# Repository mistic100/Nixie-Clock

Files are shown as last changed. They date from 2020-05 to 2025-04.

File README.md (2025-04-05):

# Nixie Clock

([Check my new clock](https://github.com/mistic100/Nixie-Clock-IN12))

This is custom design of a Nixie clock using only integrated circuits (no micro-controller) inspired my various versions of the same design. It uses IN14 tubes.



[Pictures on my website](https://galerie.strangeplanet.fr/index.php?/category/73)

Rough timeline :
- 2011 initial researches of designs
- 2012 custom PCB designed on Eagle, most components bought
- 2019 PCB redesigned from scratch on Fritzing, manufactured and assembled
- 2020 design and 3D printing of the enclosure, final assembly
- 2025 new design using the control board from my [other clock](https://github.com/mistic100/Nixie-Clock-IN12)

What does this repository contains :
- Fritzing schematics + PCB layout
- SolidWorks models
- Various datasheets

_A note on the LED controller part :_
I used an IR controller which I had laying around. It is a common anode controller where the LED I bought are common cathode, this is why my design contains a section to convert the common anode control to a common cathode. This section is not described in the parts list.

### Controls

The digits are not always on to extend their lifespan, there is a capacitive touch hidden on the side of the enclosure which will power the tubes for ~15 seconds.

There are two push buttons on the back to set the time.

## Flaws

### Minutes and hours set

Unlike the other designs, I wired the hours and minutes set buttons between VCC and the CLK input of the third and fifth CD4017 in an attempt to manually control their clock. This does not work because the CLK is already in UP state half of the time (connected to the CARRY-OUT pin of the previous counter).
A simple solution is to wire the switchs between CLK of the first counter (after D17) to Q8 (128Hz) and Q4 (2048Hz) outputs of the CD4060, making the clock advance faster.

### LED controller output

There are three resistors on the controller output which need to be removed, and instead use a resistor for each LED.

## Sources

- [Mike's Electric Stuff - Build a Nixie-tube clock](http://www.electricstuff.co.uk/nixclock.html)
- [Peter J. Wendt - My Nixie Clock Project](http://www.mcamafia.de/nixie/ncp_en/ncp.htm)
- [Tr1tium - Yet another nixie clock project II](https://web.archive.org/web/20200124190202/http://tr1tium.com/projects/nixie2)

## Parts list

### Tubes
| part | qty. | notes |
|--|--|--|
| IN14 tubes | 6 |
| IN3 indicator | 2 |
| IN14 sockets | 6 |
| RGB LED | 6 |

### 1Hz generator
This section generates a 1Hz square signal.

| part | qty. | notes |
|--|--|--|
| 32768Hz crystal oscillator| 1 |
| 15pF capacitor | 2 |
| 10MOhm resistor | 1 |
| 33kOhm resistor | 1 |
| CD4060 binary counter | 1 |
| CD4013 dual D flip-flop | 1 |

### Dividers
This section successively divides the 1Hz signal by 10, 6, 10, 6 and 3.

| part | qty. | notes |
|--|--|--|
| CD4017 decade counters | 6 |
| 1N4148 diode | 12 |
| 100kOhm resistor | 9 |

### 24h & power-on resets
This section resets all dividers when hiting 24h and also ensure a proper power-on state.

| part | qty. | notes |
|--|--|--|
| BC547 transistor | 2 |
| 1N4148 diode | 1 |
| 10uF capacitor | 1 |
| 2.2MOhm resistor | 2 |
| 100kOhm resistor | 2 |

### Tubes interface
This section connects the counters output to each cathode.

| part | qty. | notes |
|--|--|--|
| MPSA42 transistor | 47 |
| 33kOhm resistor | 47 | transitor base |
| 33kOhm resistor | 6 | IN-14 current limit |
| 150kOhm resistor | 2 | IN-3 current limit |

### Tubes power
This section generates the high voltage power required for the tubes. It also integrates a system to only light the tubes for a few seconds after pressing a button.

| part | qty. | notes |
|--|--|--|
| HVPS1364 power supply | 1 | https://www.shop-tes.com/power-supply |
| 100nF capacitor | 1 |
| 100nF 250V capacitor | 1 |
| 39kOhm resistor | 1 |
| NE555 timer | 1 | used in mono-stable configuration |
| 10uF capacitor | 1 |
| 10nF capacitor | 1 |
| 1MOhm resistor | 1 |
| 100kOhm resistor | 2 |

### Misc
This is what I used for interfacing.

| part | qty. | notes |
|--|--|--|
| micro push button | 2 | used to set the minutes and hours by shortcutting the 1Hz to the input of the minutes and hours counter |
| capacitive switch | 1 | connected to the NE555 to light the tubes |
| DC power jack | 1 |
| lever switch | 1 |
| IC terminal block | 1 |
| 2.54mm male & female connectors | |

### Hardware
| part | qty. | notes |
|--|--|--|
| M3 threaded insert | 8 |
| M3 blind nut | 16 |
| M3 standoff | 16 |
| M3 thumb screw | 4 |
| M3 screws | 22 |

### Manufactured parts
- PCB by [AISLER](https://aisler.net)  
- Steel plate by [JohnSteel](https://www.john-steel.com)  

### 3D printed parts
All printed at home on a Creality Ender 3

- Enclosure, dark wood PLA
- Tubes and indicators holders, black PLA
- Transport cover, white PLA

## License

The Fritzing and SolidWorks files are distributed under the Creative Commons 3.0 BY-SA license.

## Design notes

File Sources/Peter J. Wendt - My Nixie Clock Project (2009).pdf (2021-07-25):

# My Nixie Clock Project

by Peter H. Wendt

Rel. 0.9.5_en, Last Update: Wednesday, 2009-11-18

Most common question: "Your what Clock Project ?"

Before Light-Emitting Diodes (LEDs) and Liquid Crystal Displays (LCDs) the electronic industry used cold-cathode tubes for displaying numbers, symbols and even characters. Even though they are called "tubes" they differ from "radio tubes" by having no heater wire to heat the cathode - and therefore run much colder. They do have a glass envelope but unlike to (most) tubes they are not empty: they are filled with a gas compound, mainly neon gas. If you apply a voltage between the anode (+ pole) and one of the cathodes (- poles) the character-shaped cathode is covered with a pink to orange discharge glow.
"NIXIE" was a trademark from Burroughs Corp. for their numeric display tubes. It is rumoured that they invented this kind of tube - or at least they got patents for it. There were many different types of these tubes: viewed from the side, viewed from the top, small ones, big ones, giant sized, types where a neon glows through a character-shaped mask and arrays of multiple nixies with multiplexed wires. Even early "multi-segment" types were available, capable to display letters like the later LED 7-segment arrays.

The animation below shows the button-like, top-viewed ZM1020. It is a Nixie with 15 mm (0.6") character height.

You got the idea, right ?
Now for some technical theory.

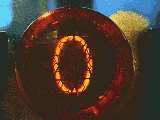
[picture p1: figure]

Basically these Nixie tubes are very simple devices. The following schematic will explain, how they work.

My Nixie Clock Project | http://www.mcamafia.de/nixie/ncp_en/ncp.htm
1 sur 16 | 25/07/2021 à 11:48

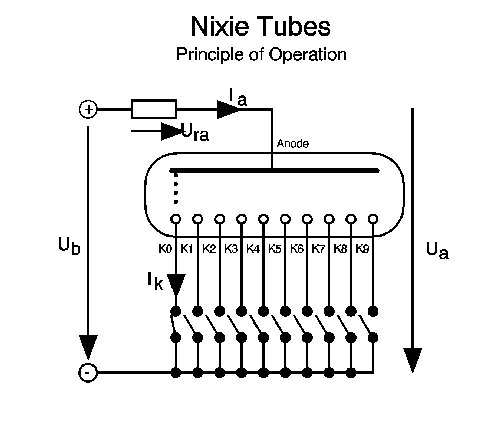
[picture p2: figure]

If you apply a voltage Ub the voltage drops across the current-limiting resistor when one of the cathodes K0 - K9 is tied to GND. The corresponding number-shaped cathode is then covered with a pink to orange glow. The values for the minimum Ub, the anode voltage Ua and the cathode current Ik needs to be taken from the nixie tube datasheet, but you can estimate 140 VDC for Ua and 2 mA for Ik as good starting values for most nixies.

If your Ub is about 220 VDC a 47K resistor / 0.5 Watts will do for some testings.
The datasheet for the very common ZM1080 / 1082 says that Ub should be at least 170 VDC and the Ik should settle at around 2 mA. Ua will then establish at about 140 VDC "maintaining" voltage (noted as Vm in the datasheet). The difference between Ub and Ua is the Ura that drops across the limiting resistor.

For a simplification we assume that the anode current Ia is equal to the cathode current Ik - you will have to tie only one cathode pin to GND at one time anyway. Nixies that use a "primer current" for faster ignition response have uneven anode and cathode currents. But we may leave that aside here.

Advantage: If you rig a multimeter in Milli-Amperes range into the (common) anode line during the testing you can track the current through the Nixie tube while connecting the cathode pins or leads to GND - without needing to meddle around with the meter wires. The unused cathode pins are left open (the term "floating" is used often). You will be able to measure voltages up to Ua on the pins not connected.
Further advantage: if you have several Nixies in a circuit, these have all one common Ub wire. If you install a mA-Meter in that line you get the total current drawn for all nixies. And can assume that the individual current is total current divided by the number of tubes you are using. This is not absolutely true - but we won't win the Noble Prize with a very precise research on that anyway.

Some quick maths to calculate the values for the limiting resistor

2 sur 16 | 25/07/2021 à 11:48

Ura = Ub - Ua -> 220 V - 140 V = 80 VDC

Ra = Ura / Ia -> 80 VDC / 0.002 A = 40.000 Ohms

Pra = Ura * Ia -> 80 VDC * 0.002 A = 0.16 Watts

Since there is no 40 KOhms resistor in the range of ordinary E24 5% standard resistors it will surely do if you pick a 43 KOhms type 0.25 Watts here, not to exceed the 2 mA cathode current.

# Calculation

## for the Nixie Anode-Resistor

Supply Voltage Ub | 220 | V
Anode Voltage Ua | 140 | V
Cathode Current Ik 2.0 | mA
Ura : | V
Ra : | K
Pra : | Watt
Calculate | Reset Cells

If you just press [Calculate] the values for the given Ub, estimated Ua and the given cathode current Ik are used and the output is the current across the anode resistor Ura, the resistor value in Kilo-Ohm and the thermal loss Pra of the resistor in Watt.
For your own calculation just overwrite the values in the upper 3 lines with what you need and then click on [Calculate] again.

220 VDC is quite a bit. How to get them safely ?

Well ... the professional approach is to have either a special transformer for the required voltages or at least an isolated 1:1 ratio separation transformer. If you live in the "low voltage" areas of the world where 110 VAC is the usual AC mains voltage you may survive a shock from the life wire. If you life in the "high voltage" areas like here in Germany the 230 VAC line voltage will surely kill you if you accidentially happen to be good grounded. A 1:1 transformer isolates the input voltage from the output voltage so you are not directly connected to AC mains. The 230 VAC that goes in comes out as 230 VAC - but you have no connection to Earth (GND) when touching any wire. You are -nontheless- toasted if you touch both wires at one time.
The professionals phrase is "galvanically separated" - it is good to know that.

Separation transformers are usually big, heavy and expensive. Not as expensive as your life of course, but enough to blow a budget. In our case however we don't need Kilowatt capabilities. A few Watts will do - so we can build our own separation transformer by simply using two small transformers "Back to Back".

The graphic below will show this simple solution.

3 sur 16 | 25/07/2021 à 11:48

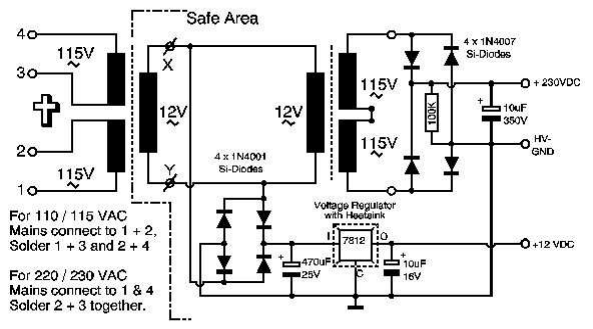
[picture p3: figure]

The transformers can be simple, relatively cheap print-type transformers with greater 4 Watts output power. The ones I used on my prototype clock are rated 4 VA (Volt-Amperes) with a single 230 V primary input and a single 12 V / 300 mA output. If you cannot get those - take two with e.g. 15 VAC or two with 8 V AC. The "intermediate voltage" between the two is of lesser importance, it is used for the logic board only. But at least the "one on the right side" must have a 230 V coil.
If you have two different transformers: the bigger (stronger) one must be the one connected to AC-mains. You cannot run a 10 Watt transformer from a 5 Watt type back to back for example. The 10 Watt has a lower resistance for the secondary coil - and the 5 Watt secondary coil is then overloaded. At least when you add load to it. It may work for some time however, but not reliably.

The 4 diodes 1N4001 for the low voltage circuit can be replaced by a block rectifier like the B40-C1000 for instance; the 4 diodes 1N4007 for the high voltage part can be substituted by e.g. a B1000-C125 rectifier bridge. This rectifier(s) must be capable to run continously with 350 V at least, so the minimum were a 1N4004 (rated 400V).

Other than that there are no secrets in that circuit. The 100 KOhms parallel to the 10 µF/ 350 V capacitor in the HV part helps - for safety - discharging the capacitor when no load is placed across the output. That's all. For your own pleasure you may add a 1 KOhms resistor at the +12V output and a red LED ... to remind you to the fact that the power supply is switched on.

With my two 4-Watt Transformers I get 15 V AC in idle between the transformers, 210 V AC idle voltage at the HV end. Also in idle the DC-voltages across the rectifiers are 18.5 V resp. 290 V DC. The high voltage however drops down to about 200 VDC when loaded with 4 x ZM1080 or 4 x ZM1020 Nixies and a total of 4.8 mA current drawn. A power supply built like that will suffice to play around with various types of Nixie tubes and get some insights on how they work.

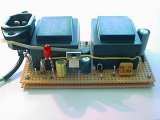
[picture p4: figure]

Important: Security - and some useful hints

4 sur 16 | 25/07/2021 à 11:48

If you use a power supply like that above you will need a medium-blow 0.315 Amps fuse in one of the AC main wires for protection when -in the worst case- the transformer goes south. You should also install the whole power supply unit in a plastic case so that it is factically impossible to touch any AC-line wire. That unit shown above is a prototype not intended to be really used that way.

If you can get one of these "wall wart" transformers that have about 500 mA at 12V AC you are fine off. In this case you only need one transformer in the clock itself and a power socket where the AC-Adapter plugs to. For the above schematic the left-hand transformer is your external wall adapter and the AC-input socket connects to the points marked with "X" and "Y" then.
Some DC-Adapters can be reworked: if you can open the case of it without destroying it - just unsolder the diodes and the filter capacitor that can be found in most of them and connect the output wires directly to the secondary side of the transformer. Then you only need the part of the power supply further above that is right from the left (input) transformer. The 12 V AC (or 8 or 9 or whatever) comes from the wall-wart and your second transformer must be choosen accordingly. And -if you go lower- the 7812 must be replaced by e.g. a 7508 (8 V output) or 7805 (5 V output). The circuit itself doesn't care much when running with anything between +5 and +15 V DC.

If you opt for that solution you can make your clock case from "more dangerous material", like steel, copper, sheetmetal, carbon-fibre or anything else conductive. You don't have the AC line fed into the unit and the worst thing that can happen is, that you shorten your electronics elsewhere and it simply doesn't work -or- damages the transformer(s).

Okay - but why building a clock from these Nixies ?

Good question. Today you can pick a lot cheapo LCD clocks from supermarkets for a few bucks. But - how do they look ? Simply boring.
Go back to the Nixie animation further above. Look at it for a while and I'm sure you can spot the difference.
I built digital counters and clocks with LED 7-segment displays and 74xx TTL-chips already in the 70's. The commercial clocks used ready-made circuits, offered alarm and such, but they looked cheesy cheap - didn't match my taste - and those who did were horribly expensive. So I made my own desktop clock.
Same reason for the Nixie Clock: a custom-made case, antique looking glass tubes somewhere in it or placed on top - a wide variety of possibly creative, unusual designs. You can make it from all material you'd always wanted to build a clock from. Wood, steel, acrylic plastic. Transparent, translucent or granite-solid.
However: the Nixie Clock described here is Just A Clock. Not a stop watch, timer, alarm clock or anything like that. You may add some "Bells and Whistles", but due to the nature of the circuitry it might be a bit complicated. More on that later.

Getting started with it: the proper timing

Heart of any clock is a source for a timing signal. Cheap AC-powered alarm clocks use the 50 or 60 Hz AC line to generate a more or less accurate clock-signal from it. Usually that would do -given that the accuracy over the whole year on the AC-line is within a 1 % range. Nontheless I'd decided not to use that. First reason was to be independent from the AC frequency. Secondly a crystal oscillator offers even better accuracy than line-AC and third I had a circuit at hand anyway

5 sur 16 | 25/07/2021 à 11:48

I used for a couple of applications in the past. Main advantage: it operates with a generic 32.768 KHz mini crystal widely available - and comes out with a 1 Hz timing pulse. The schematic below shows the circuit.

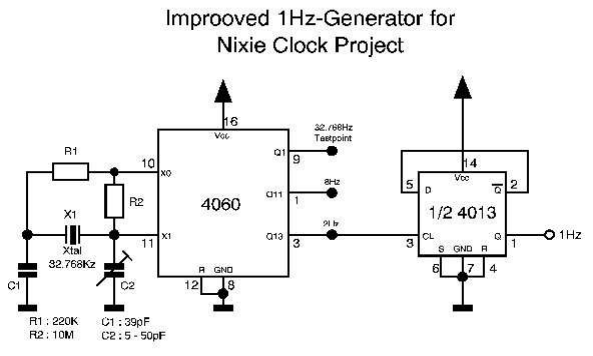
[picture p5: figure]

There are two resistors: R1 acting as current-limiting resistor and R2 bias resistor. This latter one is a) dependent to the circuit voltage applied to the 4060 divider chip and b) dependent to the current flow through the crystal and its capacity. I made good results with either omitting this one or using a 10 Mega-Ohms to start with. Your individual mileage may vary.

The crystal I used is a miniature clock crystal X1 in a round case
with 19 pF internal capacity. The "tie-up" capacitor C1 is a low-loss
ceramic type, the trimmer capacitor C2 is a standard plastic type. With a frequency counter connected to the 4060's pin 9 you can measure the buffered crystal frequency and adjust it to read exactly
32.768 Hz.

The 4013 RS Flipflop is used to divide the 2 Hz from the 4060 down

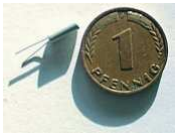
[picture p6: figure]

to the 1 Hz base clock. The second half of the 4013 might be used to divide the 8 Hz signal at pin 1 down to 4 Hz for a "fast forward" set mode - not shown here however. If you are not using the second half of the 4013: tie the pins 8, 10 and 11 to GND and connect 9 and 12. Pin 13 stays open. If you decide to use the 4013 pin 11 is your input, 13 the output.

It is highly recommended to keep the wires of the components (caps and resistors) short trimmed and the leads between the components as short as possible. If the oscillator fails to start up or dies after several seconds: make the bias resistor larger. It may go up to 10 MOhm with these miniature crystals - or even left away. The bigger HC-style crystals with higher internal capacity may require 100 KOhm - 1 MOhm bias resistors. If you don't want a trimmer capacitor you may use a ceramic capacitor of the same value as C1 as well. Doesn't hurt the overall accuracy that much.

In the meantime - after I edited this page for the last time - I had built numerous oscillators with the 4060 and got a lot responses from other folks. Alternative concepts for the trimmer position,

6 sur 16 | 25/07/2021 à 11:48

values of R1 and R2 and the C1 and C2 have been discussed.
Usually you have a datasheet for the mini xtal X1 to start with. This datasheet shows the internal capacity - which *use to be* about 16 - 19pF.
The value for the tie-up cap C1 should be 2x the xtal capacity. 39pF fits quite nicely here.
The value for C1 should be [xtal capacity < C2 < 3x xtal capacity], where 5 - 50pF covers the entire range.
Determining the values for R1 and R2 is more tricky.
While R2 could be ommitted in the best case for very dense packing of components R1 is essential for the clean function here. If it is too high the xtal fails to start - if it is too low the xtal enters "overtone mode" and the oscillator output frequency is either totally erratic or way higher than supposed.
For R1 220KOhm has prooved to be a good value, R2 should be 10M. If you have xtals larger than these micro-types your R1 needs to be reduced - down to 2K2 for a HC32 xtal and R2 might be reduced to 4M7 for stable operation.

The 4060 allowes to run at up to 4MHz @ 15V supply. If you have too much room and wouldn't care about two more 4017 dividers: pick a 3.2768 MHz xtal, leave R1 away or reduce it to 2K2, R2 to 10M, C1 to 22pF and install a 2 - 22pF trimmer. You get 200Hz at the Q13 - divided by 2 in the 4013 for 100Hz. Add two more 4017s and you are again at 1Hz with -probably- higher stability due to the higher reference frequency. However: you should not test the 4060 frequency at pin 9. The probe capacity will alter the result. You should test at O4 (pin 7) and your counter should read 204.800 Hz. The trimmer allows a change of about +/- 25 Hz. If you don't have one adjust C2 to the center, where about the half of the static "leafes" are visible. That will do to for most cases.

Step by Step: the dividers (Seconds, Minutes and Hours)

At that point we've got to hold for a moment and think about a basic design question:
"Do we want a seconds display or only minutes and hours ?"

In either case we need two 60-stage dividers. Building a clock without a seconds display saves room and driver transistors. Let's have a look at this part of the circuit.

7 sur 16 | 25/07/2021 à 11:48

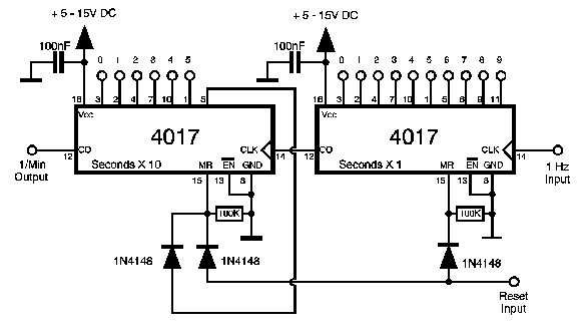
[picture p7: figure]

The CMOS chip 4017 is a "5-stage Josephson decade counter" with built-in code converter. Each low-to-high transitition (= "positive edge") on the clock input 14 advances the counter one position up from Q0 to Q9, which go to high level then. A logical "1" signal on the reset input 15 sets it back to Q0.
To count the seconds properly we have to pull the first counter reset to GND with a 100K resistor, which causes the counter to count from 0 to 9 with every clock signal. At 9 it jumps back to 0 with the next clock pulse and the "Carry Out" signal at pin 12 changes from "0" to "1", which counts the second counter one position up. The second counter has the Q6 output wired to the reset pin. After the 59th clock pulse it jumps back to "00". Any of the "Carry Out" signals changes back from "1" to "0" after receiving the positive edge of the 6th clock pulse.

The capacitors on each pin 16 are local buffer caps only. They are there to reduce the effect of local voltage sags. This is mainly an issue when the circuit is built on experimental board or with no board at all. Given you have a stable, clean supply voltage it will surely suffice to leave them away or add one or two of them on the chips farthest away from the point where the supply voltage is fed into the circuit.

The "100nF" rating seems to be a tad uncommon to some people. It has been brought to my attention that it may lead to some confusion and I had been asked if I meant "microfarad" instead (but didn't have the proper sign). No - it is Nanofarad. Or - alternatively - I could use "0.1 µF" here to clarify what I meant.

The Seconds Divider is followed by the Minutes divider. Looks in most of it like the Seconds Divider - but the In and Out is named different. Functionally they are alike.

8 sur 16 | 25/07/2021 à 11:48

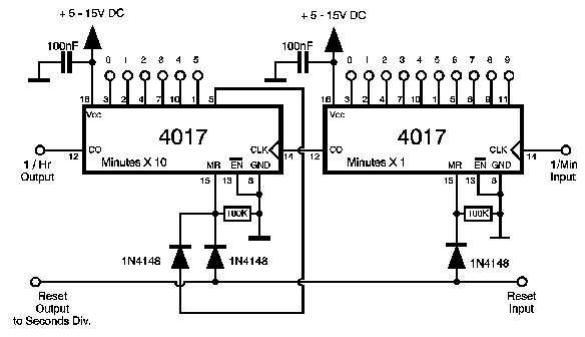
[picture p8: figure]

Now comes a tricky part. In Europe (where I live) we have a 24-hours display. We're not "AM/PM" guys over here. 24 is a bit hard to decode, since it is neither a roll-over nor is it just a single digit rollover. So note the reset-logic here. It is a wired-AND with 2 NPN-transistors that pull the Master Reset up when a "4" appears in the LSB while there is a "2" on the MSB hours display. Neat, eh ?

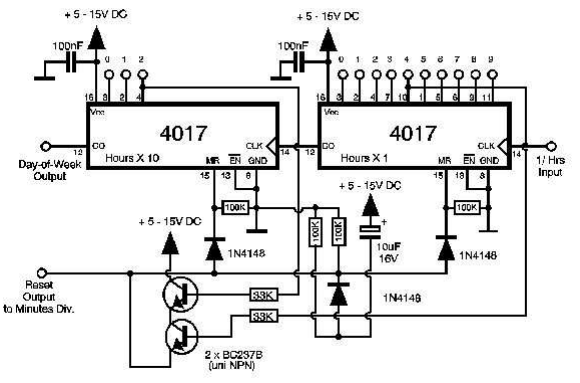
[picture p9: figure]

Also note the 10 µF capacitor, the 1N4148 diode and the 100K resistor. These three form the

9 sur 16 | 25/07/2021 à 11:48

"Power-On Reset" circuit that pulls the Master Reset line up for some time after a power on occured to bring the counters to all-Zero displays. It might be unneccessary - but you never know with these CMOS counters.
The carry-out signal from the last counter might be used to create a "Day of Week" display with another 4017 and e.g. a backlighted frontpanel. Be creative.

If you decide to have "US-style" AM-PM display you will have to slightly modify the hours divider.

The counting on the hours display does not start at 00:00 but at 01:00. All numerals need an offset. The Q0 output sets the "1", the Q1 output the "2" and so forth. Due to that you have to move the input of the 10-hours from the "Carry Out" (pin 12) to the pin 11, which advances the 10-hours with every transition from "9" to "0".
While the counting resets at one minute after "12:59" at "13" in the hours display (and not at "24" after "23:59") you need to alter signal for the Wired-AND to the reset the hours stage to pin 2 on the 10-hours and pin 4 on the 1-hours.

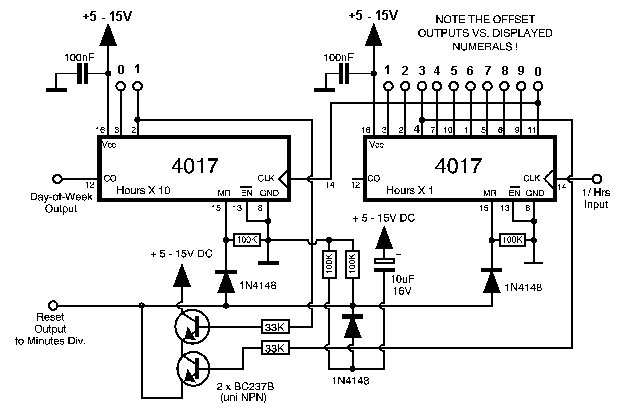
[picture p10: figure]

More power: Driving the Nixies

Problem with the Nixies is the relatively high voltage they operate with. Each cathode pin that is not grounded is pulled up due to the electron migration inside the gas-filled tube to near the anode voltage Ua. This may be 140 VDC - or above on some types. A circuit that pulls down a cathode from this "idle voltage" to GND must be capable to handle it. If you use a NPN transistor the Emitter (E) is tied to GND and the Collector (C) is connected with one of the cathode pins. The Base (B) is connected to the counter outputs via an appropriate current-limiting resistor. The "Collector / Base Voltage with open Base" Ucb0 specs for the transistor must be higher than the idle voltage on the cathodes. That's the voltage a transistor can handle when being not conductive

10 sur 16 | 25/07/2021 à 11:48

(= not switched on). This disqualifies most common transistors, since their Ucb0 is only 15 - 60 Volts.

But - there are matching transistors available. Namely those designed for TV-purposes (video stage, color final stage, deflection circuits) or various HF and switching transistors can be used. If you have access to a listing of transistors with their base data you will easily find some matching types. Most common and low-cost transistor is the MPS-A42, which is a NPN transistor with Ucb0 = 300 V, Ic = 0.5 Amp and Ptot = 0.625 Watts designed for TV video stages. In Germany we pay 0.08 Euro (about 7 cents) for one - comes cheaper if you buy 100 for example.
Also useable are BF118, BF179C, BF259, BF338, BSS48, BUW37 (all with a metal-can case) or BF413, BF420A, BF422A, BF483 (plastic case), AT1, AT2, DC or NMPSA-42 (SMD types) to name a few.

Alternatively you could tie down all cathodes to GND with a resistor of 100 KOhms to reduce the idle voltage - without starting the cathodes to glow already. In this case a more versatile transistor with a Ucb0 of least 65V like the BC174B or BC546 or BC846 should do. However - you need 3 times more resistors.

The schematic below explains the different driver circuits.

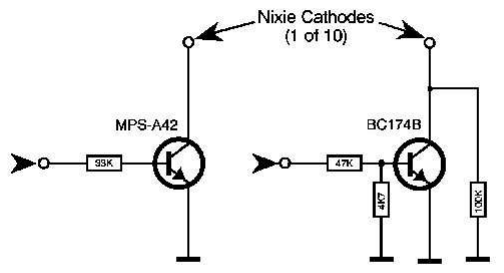
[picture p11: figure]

The left circuit is the pure simplicity: only one 33 K resistor between the counter output and the base of the transistor. While in the circuit on the right you have an additional voltage divider with a 47 K / 4.7 K resistor between the counter output and the base plus an additional 100 K "pull down" resistor that reduces the voltage between the turned-off cathode and GND.
To tell the truth: I didn't bother much with the circuit on the right side. In fact I got the idea from an old TV program display circuit that uses Nixie tubes. But the MPS-A42 transistors are fairly cheap and there's no need to switch to some low(er) voltage types, which aren't much cheaper - if at all. But maybe you happen to have several hundreds of them around ... feel free to use them.

The circuit itself is simple: the positive signal from the counter output passes the current-limiting

11 sur 16 | 25/07/2021 à 11:48

33 K resistor and turns on the Collector-Emitter path, which then grounds the cathode pin of the nixie. This turns on the neon glow for that cathode.

Under Control: Switches for setting the clock

Since this clock is only a counter it does not get the time "by automatic". However: since it has "Auto-Zero" function you could try plug it in at midnight exactly ...
So we need switches. I like clocks where minutes and hours can be set independently. And which has not to cycle through the entire 24-hours-counting in fast forward and then set the "finetuning" with a slow mode switch. I prefer setting the minutes, then the hours. Once I goof on that I don't need to re-run once again. And again. Maybe.

The solution is pretty simple. Two toggle switches, one between the seconds and minutes divider and one between the minutes and hours divider will do the trick. Look here:

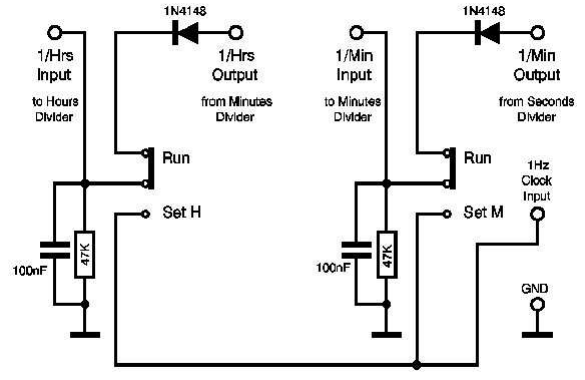
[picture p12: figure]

The common contact on either switch is connected to the input of the counter to set (minutes or hours). The resistor / capacitor combination debounces the switch a bit to avoid "scrolling" when switching back from set to run mode.
The upper (NC - now closed) contact is connected with the output of the previous counter. The Diode is for decoupling. It is not always neccessary, but might help avoiding problems, when the switch has "take-over" contacts that close both contacts momentarily while toggling.
The lower (NO - Now open) contact is connected with the 1 Hz base clock from the 1Hz-Generator. If the clock is too slow for your feel (especially on the minutes count-up) feel free to use the 2 Hz from the Pin 3 (Q13) of the 4060 directly or even use the 4 Hz signal that can be generated from pin 1 (Q11) of the 4060 and the second half of the 4013 Flip-Flop. Or use pin 2 (Q12) on the 4060, which offers 4 Hz already.
12 sur 16 | 25/07/2021 à 11:48

Ticking the seconds: A blinking colon

Those who opted to build a 4-digit clock with Hours and Minutes only (and save 16 transistors and 16 resistors at least) may wish to have something that indicates the seconds pacing on. Analogous to the odd blinking ":" on other digital watches.
Easy done. If your Nixie has a decimal point you could use one of those. Nixies that have a decimal point to the right of the number should use the one in the 1 / Hours digit (LSB), with a left-side decimal point you use the one in the 10 / Minutes digit (MSB). No special treatment required. The anode current on the Nixie goes up a bit - but that shouldn't harm anything.

Those who use Nixies without decimal points or aren't attracted much by the look may use a single neon-lamp in the middle between the hours and minutes display. See the schematic below.

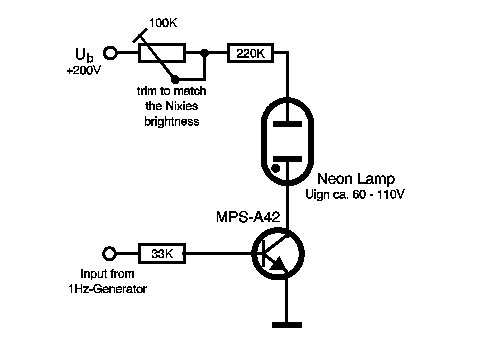
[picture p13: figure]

This is how the single, middle flashing neon lamp looks on my second prototype: it is a relatively long and slim lamp I recovered from some electronic crap in the early 70s ... almost 3 decades later it came handy to act as a blinking colon in a home-made Nixie Clock. Life is funny.

You could also use a LED - or some "Magic Eye" tube that alters height / angle during the seconds ticking. But "real tubes" require a

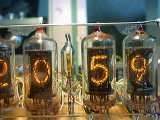
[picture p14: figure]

heater supply which is several 100 mA normally - while the entire circuit with the 8 CMOS chips, the driver transistors and such takes less than 10 mA. The Nixies take another 5 mA from the 220 V supply - and that's all. If you stuff in a "radio tube" you will have to extend both: your low-volt and high-volt supply as well. So far you come away with about 6 Watts electric energy - given that the two transformers have an efficiency of about 80 %.

Bells and Whistles: Adding extra-functions

13 sur 16 | 25/07/2021 à 11:48

(Not yet fully approved)

An easy method to add an extra function is using an integrated sound circuit. Usually these chips are positive-edge triggered. Means: you pull the input high and the sound plays. Given you got a chip with a "Big Ben" bell tone you simply add an AND-gate output (or two transistors as for the "Hours" reset circuit) to the sound-chip "activate" input. The AND-gate input is connected with the "0" outputs (pin 3) on the minutes divider 4017s.

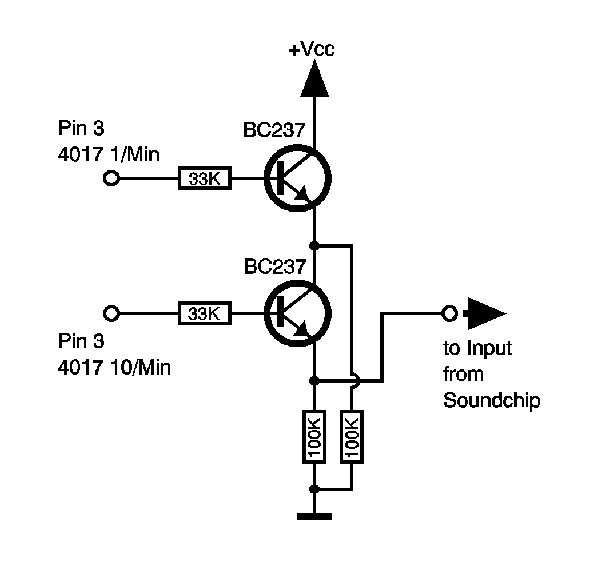
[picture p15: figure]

Result: any full hour when the display jumps to "00" in the minutes the sound is triggered. Hint: include a switch to shut off the sound. Sometimes these "good" ideas turn out to be somewhat ennerving on the long run. (Big Grin !).

Finally: some pictures from my prototypes

So far I made three different prototypes. After some testings and trials the circuit has stabilized to the components shown above. There is however a lot room for improovements or changes, add-ons and whatnot. Especially the switches for setting the time are subject to permanent change. A printed circuitboard is also (yet) missing, but I'm working on it.

Here are some pictures of the two working clocks.

14 sur 16 | 25/07/2021 à 11:48

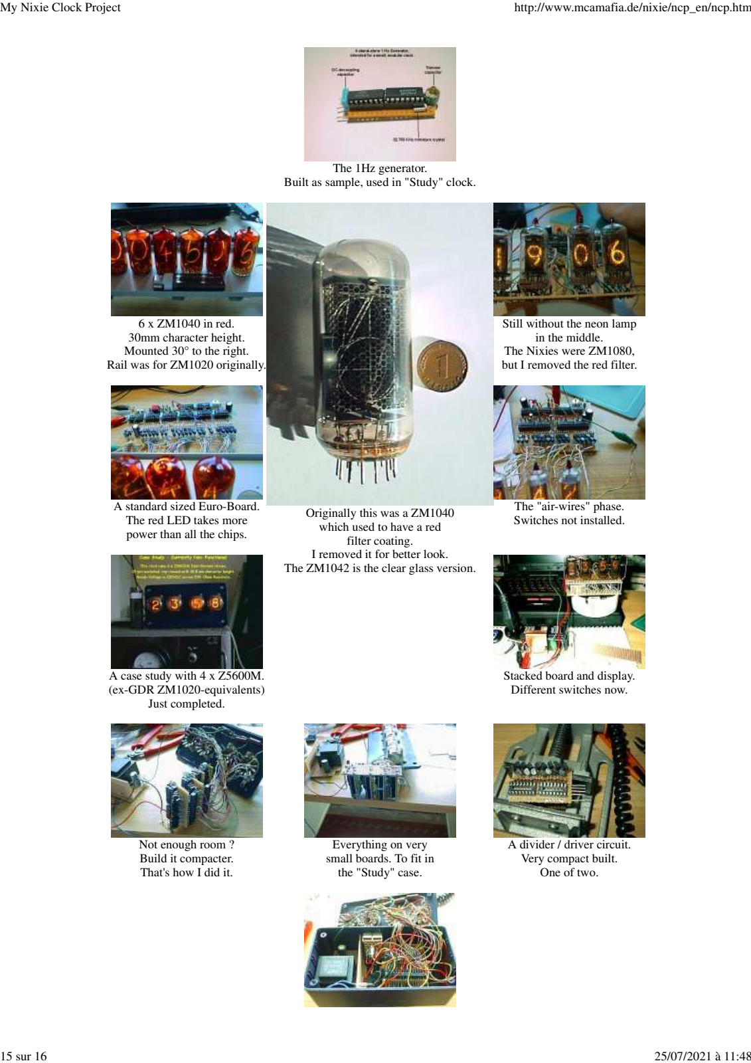
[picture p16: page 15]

The 1Hz generator.
Built as sample, used in "Study" clock.

6 x ZM1040 in red.
30mm character height.
Mounted 30° to the right.
Rail was for ZM1020 originally.

Originally this was a ZM1040 which used to have a red
filter coating.
I removed it for better look.
The ZM1042 is the clear glass version.

Still without the neon lamp in the middle.
The Nixies were ZM1080,
but I removed the red filter.

A standard sized Euro-Board. The red LED takes more
power than all the chips.

The "air-wires" phase.
Switches not installed.

A case study with 4 x Z5600M. (ex-GDR ZM1020-equivalents) Just completed.

Stacked board and display. Different switches now.

Not enough room ?
Build it compacter.
That's how I did it.

Everything on very
small boards. To fit in
the "Study" case.

A divider / driver circuit. Very compact built.
One of two.
15 sur 16 | 25/07/2021 à 11:48

A look inside.
Yes - it is pretty tight filled..

Other related Topics:

My Nixie Tube Mini-Tester - My Little Nixie Collection A "7-Segment-To-Nixie" Decoder (very strange thing) Dimming the Nixies - A Nixie Clock For Everyone ... !

© 2001 by Peter H. Wendt

Maintainer Notes: all tips given in this document are without any warranty.
If you accidently kill yourself, burn the house or blow everything - your problem. Switch your brain on, think, reconsider and then act. But first: Think !
You may however pick anything you like from this page if you quote the original source.

Feel free to leave me a note, reports, pictures or ask questions if you like.
I try to respond if my time allowes, which is not always the case. Sorry. I have a lot hobbies and a job.
16 sur 16 | 25/07/2021 à 11:48

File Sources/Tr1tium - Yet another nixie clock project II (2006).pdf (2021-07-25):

The Wayback Machine - https://web.archive.org/web/20200124190202/http://tr1tium.com:80/projects/n…

## yet another nixie clock project II

almost three years of no work on the first nixie clock and the bug has bitten. it's time to start again! and, who'd've thought, but after the start in oregon, the move to new york and taking the clock to work to show colleagues and interns, then back home again, the darn thing still works and fast forwards...wow! ok...on with the show.

as you may have noticed, the first clock was really one of the first projects i had ever done and i learned *a lot*. on top of that, my skills greatly improved over time. heck, check out the new timing circuit in the clock to see the difference. i've still got a lot to learn, but only time will tell. anyway, the hope here is to keep everything a lot smaller and a bit more modularized. plugs here and there and have a few pieces that can be disconnected from each other and reconnected so that they will be easier tested and one day fit inside a nice looking project box/display/something like that. that's the hope anyway...

once again, i'm using peter wendt's nixie clock page for reference and only posting changes and things i'm doing so you should check it out to see what's going on.

as a note about updates, additions and the dates: sometimes i put the date in to help keep track of where i'm at and what's going on update wise. i guess it's a little blog-esque. most of the time i update and fix errors and don't mention it unless it's bad and nasty.

11/12/2005: so, the first thing on the list was parts. last time i went around, ordered parts, visited stores, drove here and there, ordered parts, drove here and there...it went on and on. this time i tried to piece together everything i'd need and order it all at once and just ordered it from mouser. they've got it all... but, for some darn reason i still went to radio shack and bought a few things. weird i know.

the parts arrived and the first attempt was the power supply. it's really the original design, but i did use a 115V -> 12V AC adapter so it would hang on the wall and not be stuck inside the clock. it takes up less space and is suppose to offer some safety advatages. on top of that, i stuck an LED on the 12V output (after the voltage regulator) so that when it's plugged in i'll know if it's on or not. here's the design and a few pics.

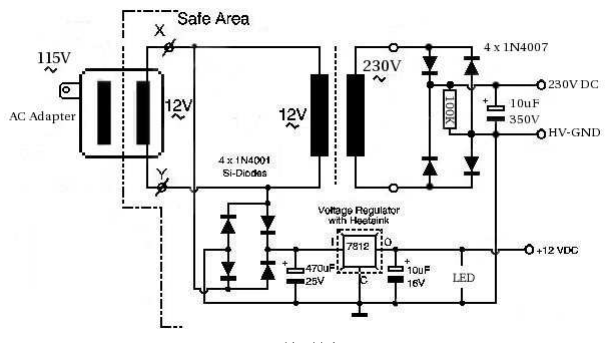
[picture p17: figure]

and the original

yet another nixie clock project II | https://web.archive.org/web/20200124190202/http://tr1tium.com/projec...
1 sur 13 | 25/07/2021 à 12:00

the 4 pin on the left is the 12V AC in from the adapter and the "green" plug is actually a male/female adapter together for the 230V out. the white 2 pin in the middle, by the heat sink (you can barely see) is the 12V regulated out. click on them to see bigger, commented pics.

and the darn thing even tested out ok! the regulated voltage hits 11.96 which is pretty darn close to 12V and the step-up transformer is reading 251V because it's not under load. you'll notice that this time around i'm using a straight 12V -> 230V transformer instead of the 12V -> 115V and voltage doubler like i did before since i got a lot of my parts from radio shack before i discovered mouser (or any real dealer), and of course they didn't have any transformers like that. this time around, since i got all my parts from mouser, the transformer existed. either way, it works and you do learn a lot as to why it works. as i thought about which i'd rather do i figured this would be good to try out since i didn't do it last time. course, if i understand right, the output from the transformer is much cleaner than from a voltage doubler.

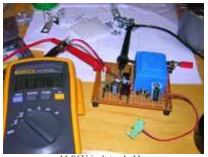
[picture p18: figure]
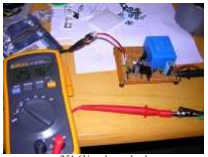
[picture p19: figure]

11.96V isn't to shabby | 251.6V under no load

i ordered the tubes from sphere research again, and, once again, no problem. a call, a payment and like 3 days later the tubes arrived. this time i got the siemens zm1332 tube. a little bit smaller than the tubes from last time, but they were brand new this time and sure look nice. <g>

and it even lights a tube!

a grounding side note, since this got me last time... you'll notice that if you compare the voltage doubler power supply of the first clock and the diagram of this power supply (see above), there's a connection between the high-voltage ground and the low-voltage ground present. turns out, and i didn't know this originally, that ground doesn't equal ground. eg. low-voltage ground is different from high voltage ground. so, when i built the first clock the nixie tubes wouldn't light up even though everything was counting correctly. this was becaue the high-voltage ran through the transistor, but there was no low-voltage ground, so nothing happened. i gave my dad a call, talked with him a bit and he told me to connect the low-voltage ground to the high-voltage ground to solve the problem. i did, and wham, the problem was solved. the clock started working. so, was this a big "it worked one time"? nope. in the blinking tube movies below the 12V runs into the transistor and the only ground directly connected is the high-voltage. since this power supply connects low-voltage ground and high-voltage ground, it worked, just like it was suppose to. so, hopefully this makes sense to anyone but me and isn't complete bull. :)

11/19/2005: after the power supply it's time to make the timing circuit. i actually started last weekend, but it didn't go so well. everything else went amazing, considering it was the first time at such a project in 3 years, but when i got to the timing, nothing. so, back to work. but! this time around, instead of doing everything with a soldering iron i used a pluggable breadboard. and that made it good. in about an hour it was working and it looks like the reason last week didn't work is because the 4060 chip is blown and some of the capicitors from the radio shack mixed box are bad. how'd i know last weeks chip was blown? i found that the 4060 intakes 11.96V and outputs ~6V...not to good. on top of that, it's hot as heck like it's just burning off voltage. something isn't right with it. luckily i have a second one, so i used it and, sure enough, with the plans i had originally, it works! and it stays cool.

2 sur 13 | 25/07/2021 à 12:00

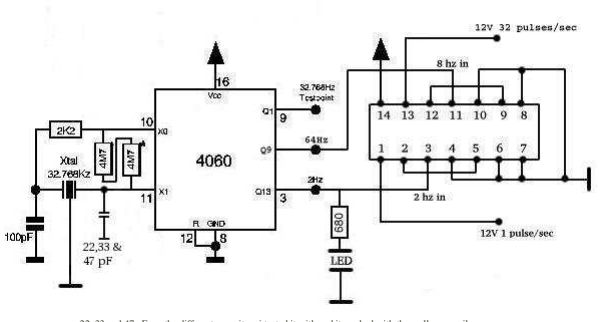
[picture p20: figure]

22, 33 and 47 pF are the different capacitors i tested it with and it worked with them all. your mileage may vary. note: timing has been redone a bit, so see below see the original

afterward i soldered everything together and put the 4060 in and...nothing! what! i moved it back to the test and still nothing. then i found that it's outputing under 11V, around 10.5V to be exact. i have a bad feeling about this one too so i've ordered some new 4060s from a different manufacturer and we'll see if i just screwed them up, or if they're really that bad.

11/20/2005: i decided to pull the 4060 from the old clock and test it out. and, what do you know, it worked in the test setup without a hitch. the circuit i built needed a bigger capacitor, so i changed it from 22pF to 39pF and it worked. the led blinked without a problem. so, either the chips i got were bad, or i wouldn't trust them. the one that worked (and i've reordered) is the NTE-4060B.

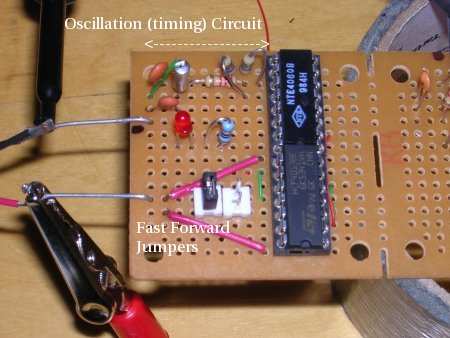
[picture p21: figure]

this circuit has the jumpers because i wanted to choose between two different fast forward speeds without having to resolder. the circuit is the same as above, it just has the jumpers inbetween the 4060 Q9 outpin and the flip-flop input pin 11 (i'll update it soon). the two speeds are 4 and 16. i was going to use 8 and 16, but the 4060 doesn't have 16Hz out. i'm sure there's a reason, but it seems weird...

3 sur 13 | 25/07/2021 à 12:00

12/4/2005: i got the new nte4060 chips, put the old one back, inserted the new one and everything worked just like it was suppose to. yay! so, in playing around i bought a cheap plastic container so it could be the first box (it's just a test really). i drilled some holes, mounted stuff and we'll see how everything fits as we go along. the biggest thing is that i tested the nixie tube with the timer to see if it would turn on and off every second and how the tubes would look. as a side note, next time i put chips next together i'll put at least one space in between. the 4060 has flat edges, but the flip-flop doesn't. it buldges a bit and getting the two to fit next to each other like this might have been pure luck. but, it's working for now. <g>

12/11/2005: oscillator changes at hand! originally i built the timing circuit, got it going and was happy. but, it takes around 6 seconds to get going. so i decided i'd play with it and see what i could do. i tried adding a bit more capacitance to the 22/33/47pf side of the crystal (see above) and by darn, that sped it up a hair. then, out of screwing around, i added a bit to the 100pf side. boy, did that have a big effect! the start-up time dropped from six seconds to around 3 (btw- this was all on the plug board). so i calculated the capacitor ratio between the two sides and found out it was about 5.2. i don't know why i did this. it just seemed like a good idea. since i have a 39pf soldered in i had to test it with a second 100pf capacitor, doubling the pf on that side. wow! it dropped from a 6 second startup time to ~1 second. so, i sold myself on it and soldered it in. that was saturday. then, on sunday, i figured it was a bit strange. why did it work? so i dug around a bit and tried to refamiliarize myself with timing, crystals and osciallation. if you're interested, i found some good links at ECS Inc. (i have the tfc-3x8 crystal), wikipedia and crystal oscillation, a pdf description of circuit design, and an in depth discussion at google groups. anyway, i decided to look at the docs for my crystal and found the circuit design recommended varied a bit from the original. so, i tested it out (see below) and on the first round using a 22pf cap the crystal started osciallating in about 1 second! i switched to a 39pf (note that both are 22 or 39 unlike 100 and 4-40) and it started the same, in about 1 second. then, i attempted to do the calculations to find out what capacitor size would give me the "load capacitance" for the crystal as defined by the manufacturer and came up with 15pf (see the pdf description, page 3 i mentioned above). so, i switched to that and the darn thing starts up in less than a second! it's kinda crazy. here's the different layouts and even movies to go along! and the original 6 second start can also be seen.

with 2 100pf caps

-->

using either 22pf or 39pf caps. note the 2K2 to 330K resistor change.

-->

using the 15pf for
calculated "load capacitance"

granted, this is all on the plug board and we'll see if i can solder everything together correctly...but it looks good. in comparison, it takes the version one clock a bit over two seconds to start up, so this is much, much faster. but, keep in mind, you should probably check out the docs for the crystal you have and see what they recommend for a circuit design. that's what seems to have solved the "how long it takes to startup" details. i guess we'll see for sure...

12/18/2005: today i soldered the timing circuit together i had tested out in the plug board and it was a success. the little led starts to blink in what must be around a half second and when i plugged it into the test nixie tube you can't tell. you push the power button and it just starts flashing each second. watch it if you want...

the layout is pretty similar to the original, but here it is, and it looks as though checking to see what the crystal manufacturer recommends will be a lot of help. the design might be just like the original, it might be like this and it might be different. i know, that isn't really helpful is it. :) (here's the doc for the ecs-3x8 crystals i've used)

4 sur 13 | 25/07/2021 à 12:00

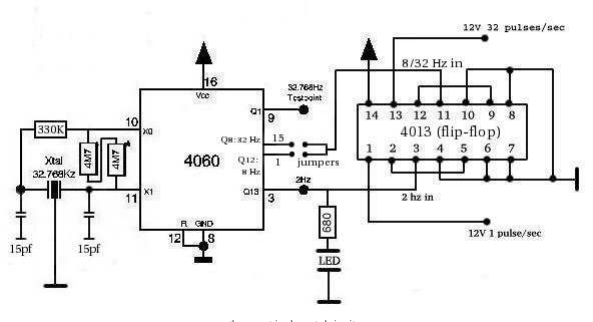
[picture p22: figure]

the current implemented circuit

and, as i've mentioned, i wanted to start putting things in some container so i could see if they were small enough and get some idea of how the parts were fitting together. plus, it would give a good place to mount switches and the a/c adapter plugin. so i got a cheapy tupperware container and started mounting things inside. who knows if this will actually work, but we'll see...

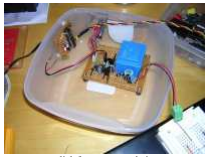
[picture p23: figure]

click for commented pic

12/26/2005: now that we've got the timer going and the power supply ready it's time to move to the world of counters and nixie tubes. so, first off, i worked with the seconds decade counters. for weeks now i've been attempting to visualize, draw out and think about how i'll lay this stuff out in an attempt to minimize wire criss-cross and help the problem of all the little things that will infest the board. so, in a first attempt i put the decade counters on a small board about 2x3 inches.

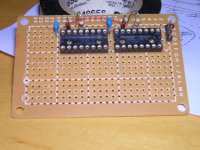
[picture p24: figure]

see the original seconds and minutes decade layout

but, after i built it, and before i added all the good stuff to make the nixie tubes cycle, i decided that in order to link three of these together there would be to many wires and connections and it would be better to go back to the single board layout like i did before. so, the next day i worked on this i laid out a few more sockets and rebuilt the seconds decade counter area.

5 sur 13 | 25/07/2021 à 12:00

see the original seconds and minutes decade layout

i did some tests and was able to see that it is counting corectly, just like the first time! if i held the volt meter on one of the pins of chip 1 (say 4) and waited for the DMM to blink 12V, then i would count "one-one thousand, two-one thousand..." and around the same time i hit 10 seconds, it would blink 12V again! then, if i go to the second decade counter i can see that pins are live for 10 seconds like they're suppose to be and i can follow from pin to pin and see that things reset and go from 0 -> 1 ... 4 -> 5 -> 0 just like it's suppose to. i even hooked up the test nixie tube i have in the plug board to the first counter so that evey ten seconds it would blink on for one second. then, i hooked it up to the second decade counter so that it would stay on for ten seconds out of every minute. i also tested the reset to see if that would work and surprisingly, it did. i think things went well today. :) since things are counting right it looks like it's time to add a few tubes and actually get things ticking...

12/30/2005: i've had a nice surprise of off time during the week and been able to work on the project. as of yet, the circuit hasn't changed from the original layout so i've plugged along and gotten the seconds ticking! i fought and fought about how to lay this out for now, and finally decided on the single board with the tubes at the front. as you'll see though, there are two main sections: the counters in the back and the tubes in the front. theoretially, when i finally figure out how i'll mount this stuff, the board can be split into smaller pieces and the only thing i'll have to take out and redo is the connection from the transistors to the tubes. we'll keep our fingers crossed... so, here's how it's starting to look:


notice i've got the hv ground on top so i can easily run the resistor straight in


i'm trying to use as little crossover and wires that crossover as possible on the bottom. (ignore the counter -> nixie wires, they're temp)

the top colon is actually back a little bit, but it seems to look ok

another cruddy picture

i still haven't figured out how to take a decent picture, and you can sure tell from the above two shots of the seconds with the colon. the dark one is the "moving body" feature of the camera and the second is just without a flash. maybe one of these days i'll figure it out and get something decent up.

6 sur 13 | 25/07/2021 à 12:00

the biggest thing that comes to mind is that i changed the resistor on the HV power to the nixie tubes. i was using 47K as a general one, but after rereading, referring to the docs and using the calculator on peter's page i changed to 33K. this is even a bit off. before the resistor the voltage measures 230V (Ub), after it was 145V (Ua) and the cathode current from the docs is 3mA (Ik). so, assuming i measured right and have it all right in my head then it calculates out to 28.333... i don't have any 28.333 K resistors so i used a 33K. interesting and we'll see what this does as everything seemed to test out the same after i replaced the 47K resistor with the 33K.

so, a short update as the weekend is coming...

but i know you wanna see what it looks like in action...

1/2/2006: the minutes have been added. more to come and i'll mention my "mistake" on the power to the nixie tubes that was easily solved. :)


one of these days i'll figure out how to take a good photo of the tubes...

and the minutes in fast forward mode....

so what was the mistake on the power to the nixie tubes? somehow i had it in my head that the incoming voltage to the nixie tubes was all shared through the same resistor. interestingly enough, it wasn't until the 4th tube was hooked up that an obivious problem hit. the numbers were only partly lighting, for example, the top bar of the five wasn't on, or the the lower piece of the number two. on top of this they were so fuzzy that they were albout twice as wide. so, what was the solution? each tube has to have it's incoming voltage through it's own resistor. DOH! and that makes sense. the current resistor is calculated for a 3 mA draw (for theses tubes). with 4 tubes it would have been 12 mA and the resistor needed would've been different, let alone with 6 tubes. ooops. so, theoretically, it could be done, but each time i added a tube i'd have to change the resistor and it's probably much better for each tube to have it's own. here's the nixie tube reference drawing:


each tube with a resistor

1/15/2006: some oddities with the fast forward switch popped up. it turns out that switches apprently don't do a very good job of absolutely cutting off what they're doing and seem to short. and so were all on the same plane, this is between the seconds divider output and the minutes divider input. by default it just takes what it gets and passes it on for normal operation. but there's a

7 sur 13 | 25/07/2021 à 12:00

momentary switch that when depressed takes the output of the the second output half of the flip flop. by default, this is 4 hz. if i change the jumper, it's 16 hz.

when i first installed the switch so i could fast forward it mostly worked. sometimes it would jump ahead at what seemed 16 hz or even faster. then i noticed that if i depresed the button part way it would jump wildly, then once it was depressed all the way it fast-forwared at the correct speed. on release it even tended to jump from time to time. weird...very weird.

i did some digging, wondering if the switch i bought was a piece of junk or the wrong type and found out that had i looked at the plans i probably wouldn't have had this problem. turns out that peter had this already planned. besides...i wouldn't have been able to come up with it. so after playing around a bit i found it worked wonderfully. i did have to increase the capacitor size though from 100nF to 10uF so there's definately something about the switch involved here, but it doesn't jump ahead anymore and seems to be behaving itself. here's the current solution:


the original

1/16/2006: we're getting closer to having the hours going. <g> after adding the next set of colons i stuck in a switch so that you could choose between the two fast-forward rates i have without having to change the jumpers. there's a picture of the silly little thing i had to build below and an example in action if you really can't wait.

two more colons | and the back side

a computer jumper cable would be better, but oh well

and after that came setting up the power on zero capability and the 24-hour zero function. once that was done and tested out it looks like we're ready to go and add the last couple tubes to see how it will all look for the first run. then comes the real nasty part. figuring out how to put everything inside a box so i can just plug it in and let it run. hmmmm...

an interesting side note that might bite me later, but i don't think so. in the plans all the decade counters have a capacitor tied into pin 16, their 12V power input. well, the first five counters have this because by the time i hit the last one there were no holes left and i couldn't figure out where to put it. but it hit me that in this case the power in was a single line in parallel to each chip and each capacitor was hooked to that line and thus to each chip. so, i figured that i could get away without the last capacitor since all six counters should be sharing the five that are already there. so goes the theory in my head anyway...

1/22/2006: and the first round of the clock is a go!

8 sur 13 | 25/07/2021 à 12:00

and you can watch a short movie and see what it looks like. 24 hour roll-over coming soon...

it ran for a few hours last night and it's been running all day today. now i'll run it most of the week and see just what kind of job i've managed to do and how it works when on for more than 5 minute test runs. <g>

(3/12/2006: i realized i didn't have anything up regarding how the hours are put together, the clock is zeroed on start and it goes back to zero at midnight, so here's the schematic along with the original. note the only difference is the 2.2k resistor on input to both 4017s.)

so, what's on the list? well, it needs a case and that's still a mystery. plus i've got an idea on how to make it battery powered so that when you unplug it, it will still work for a bit. the "bit" is of course the interesting part and we'll see just how long that goes. i'm also thinking about adding a couple extra things, like the ability to reset the seconds to zero, and maybe redo the fast-forward jumper area so that instead of two two-pin jumpers it's just a single three-pin jumper like between the seconds and the minutes. that would problably make the fast forward speed selector switch connection a lot nicer. but, the two big things are the case and converting 12V dc to 12Vac so batteries will work. that's an interesting one... here's a couple spots i'm eyeing right now: a 12V -> 120V schematic, a 12V -> 9V schematic, and some "simple" dc inverter schematics. we'll see if i can figure this stuff out since it's new to me.

1/29/2006: and "most of the week" turned into the whole week! the clock's been running since about 10:00am on sunday the 22nd until today, non-stop. wow...that's really kinda surprised me as well since i never ran the first clock i built unless i was in the same room, like at work. i was afraid it would catch fire and burn the building down. but, this one has been going strong (knock on wood) and looks like it's passed the first test. <wipe sweat from forehead/>

the 12V dc -> 12V ac conversion is still up in the air though. luckily, i've gotten a couple ideas and i think one of them will work. details to come...

2/7/2006: and we've hit over two weeks now! yup, it's still going. i had a little drive to turn it off and play with a few things, but i just couldn't do it. since i was about to hit two weeks i scrounged up some batteries and was able to hit 12V for the new idea that hit me in the head.

instead of powering the backup with a battery, why not do it with a capacitor? a really big capacitor! hmmmm... i originally got the idea from a supercap 9V battery i keep running into that i've seen at www.hackaday.com, in make magazine and other places around the web. so, in playing around, i bought a 4700 micro farad capacitor from radioshack and stuck it in parallel with a bunch of others i had sitting around. in parallel they all add together and the overall capacitance was a meager 0.00832 farad. short of the supercap, but it sure gave some interesting results to play with.


and even a movie to boot (and this one is really the same but what the heck

even with that the led blinked for over 30 seconds once power was removed. granted, it got dimmer and dimmer as time ticked by, but was still interesting to play with. once i connected the meter and was able to watch the voltage drop as time passed on i was able to see that although the led blinked for 30+ seconds, it only stayed above 10V for, at most, 5 seconds. but, once again, this is only .00832 farad, so we'll pretend it's a straight line and it did it for 4 seconds. that means that a 1F supercap would stay above 10V for 480 seconds. but, the led blinked and it continued oscillating (and the oscillator was the same as is used in the clock) for over 30 seconds so that would mean it could continue for around 3600 seconds. this is just guess work, but i like it.

9 sur 13 | 25/07/2021 à 12:00

so, how do you implement it? that's the good question. digi-key has the cooper-bussman aerogel supercaps and these look interesting. the b series has a working voltage max of 2.5V but you can put them in series to increase this voltage. however, caps in series apparently does some really weird things to the actual capacitance total (although everything is actually equal in the end). i found a good explanation of caps in series and parallel. cooper-bussman also talks about the best way to create the series configuration in their application guidelines and as most of the electronics world is new to me and i need refreshing all the time i had to look up voltage dividing again and found something about the resitor voltage divdier. now, back to implementing it...ya...i'm still working on that...

2/16/2006: i've been out working in mississippi and haven't worked on the clock. still working on the back up super-cap idea, but nothing really to report. the only real thing is that the dog struck and the clock looked dead!

all numbers in the nixie are lit!

while i was out i decided to leave the clock on so it could continue the wonderful history it was making. but, while i was out my poor girlfriend told me the dog got excited, like super excited, and wacked the coffee table where the clock is sitting and knocked it ajar. i told her to just turn it off and not to worry about it. biting my nails i wondered what had happened? did something short? did a wire come loose? did the high voltage short across and burn out, well, the rest of the clock? hmmm...

so the day i got back i turned it on and sure enough it wasn't behaving. the timer worked fine as the led blinked like it was suppose too, showing that the crystal started oscillating. so i lifted up the board to look inside and noticed something...

the ground wire is ajar!

yup, the ground wire is ajar, not connected, no ground, nada. this is where the oscillator gets it ground and then passes the ground on to the decade counters and that side of the board ("that side of the board" meaning where the decade counters are mounted). so, if there's no ground, then that would definately be a problem. very interesting though that the led lit up and the oscillator started oscillating without ground none-the-less. interesting... but, once the ground was reattached it started up fine and we're back on track!


the ground wire is reconnected

2/26/2006: this is short and i'll go into more detail later, but the alpha version is working although it doesn't backup for very long and it's probably a "design issue" since i've no experiance at this. anyway, here's the initial circuit i've put together and played with this weekend. in short, the whole idea is to take 12V in and turn it into 5V since the ultra capacitors have a max voltage of 5V. you could do this with resistors only, but i put the voltage regulator in becuase i don't trust myself. then, i used the LM2577 step-up

10 sur 13 | 25/07/2021 à 12:00

voltage regulator to turn it back into 12V. i know, i know...kinda silly. but it works. i tested it out and was able to get 60 seconds of downtime with 1F and 180 seconds with 2F. now, it seems that something is screwy and it should be longer. i forget where i did the calculations, i think it was at the cooper-busman website, but even then, that seems really short. i'm sure it has something to do with the circuit...


i ordered the wrong type of lm2577 and had to "fix" it

before... | after!

the beginning layout in the plugboard

3/5/2006: my head hurts...i've tried so many differing things in an attempt to lenghen the time it's ridiculous. put this here, that there and most of it makes no sense since it's just stuff i've made up because it make a little bit of sense. why did 2F only give 180 seconds?

the testing was all done on a second oscillator i have, built the same way as the first, just not directly plugged into the clock to make things easier. i measured the current draw to the oscillator and if it registered (the meter is analog) it was less than 10 mA, so it should be more than 180 seconds, much more. my mind was blank, so in a last ditch effort i scrapped the step-up and just plugged 5V directly in.

it ran fine off 5V and when i disconnected it continued to run for just over 19 minutes. that was 19 minutes off of 1 F instead of 180 seconds off of 2 F. looks like the step-up is eating something horrible. so, i ditched it. then, to make a long story short i had to figure out how to use the caps with the clock, and i can't just use 5V there, so i tested out some 0.33 F caps i have in series so they would just work in the 12V setup and not need the 5V regulator or the 12V step-up. turns out, that if my math is correct, there is an overall capacitance of about 0.11 F and that kept the counters going for about 120 seconds! not bad for 0.11 F vs the 2 F last time. but, that's not the end of the story...the counters did continue to work, but everytime power was restored the clock reset to zero. this will get fixed!

11 sur 13 | 25/07/2021 à 12:00

4/2/2006: it was just driving me crazy and i had to take a break. the reset was taking place no matter what i did...and i tried so many different things it was pretty much just beating my head against the wall. so, it was time to take a break. not that it's really related, but one of the things i did besides waste time, watch tv and do about nothing was install enlightenment dr17. i'm very impressed...but that's another story, so back to the clock today...


in the many trials i decided that by doing this i'd switch to powering the clock from 12V to 5V since the counters and evrything would still work off of that. and, really all i'd need to do is change the voltage regulator from a 12V to a 5V and it would handle it fine. so, i did, and by some weirdness today i stuck a resistor in. yes, that lone resistor between the voltage regulator/ultra capacitor and the rest of the clock. and time after time the clock went to sleep for one, two, three and four minutes off a 0.33 F capacitor and came back on without zeroing or advancing irregularly like it had done before. to test it i took the resistor out and it wouldn't work. it would zero, or advance and show that it had been powerless for 4 minutes even though it was only 3. something weird. put the resistor back in and all was fine. then i stuck in a 1 F cap and it went to sleep about 13 and a half minutes without a problem. i was timing it and powering it back on when the voltage hit around 1.9V. it might go longer, but everything was working so well i just had to end it there.

now there is one slight problem. when you turn the clock on it's a bit dim, and takes a few seconds to become fully bright. this is because the super-cap is "charging". why does this happen? yet something else to think on, but at least it starts ticking right away, still less than a second!

6/10/2006: so after much thought i knew that i would have to redo the power supply to add in the capacitors for backup. i would have to redo the timing circuit, just because...and in the end with all the switch additions and little tweaks i have planned in my head, much of the decade counter section would need redone too. what does that mean you ask? generation three! there's no doubt that i will build a new clock, and this one actually has kept working so i've gotten use to it since i turned it on back in january. each time i thought about working on it, i actually didn't want to because i was afraid i would break it and i wouldn't have it ticking away anymore. so, i decided to box it up and see if i could figure out how to put it in some sort of "project box". boy...not an easy task. somehow, and this really was a miracle, i was able to fit everything into one of the project boxes from radio shack. thank goodness for the dremel!


the power supply and counter is in | i split the counter section from the nixie tubes and was able to wedge it in the project box.


a test for the hook-ups from the counters to the tubes...it's a go!

12 sur 13 | 25/07/2021 à 12:00

all the pieces before insert


the front...oooohhhh | the back...aaahhh

and of course i had to start playing with something else: the dekatron

TIPS:
1) you need to have some way to measure voltage and hz. i have a fluke 110 digital multi meter (dmm) that measures volts, hz, capacitance, resistance and a couple other things. it works great. this is very important as trouble shooting this stuff will be impossible without one.
2) test along the way!!! if you build it (or even pieces) all at once, you'll never be able to figure out where the problem is. test and troubleshoot along the way.

Some refs:
- a fairchild 4013 pdf
- a fairchild 4060 pdf
- the zm-siemens nixie pdf (has the 1332)

thanks to peter wendt for the great directions, pictures and help.
disclaimer: you are COMPLETELY at your own risk when trying to build anything referenced on this page. i am not your mom, think for yourself. if you can't, don't start the project.

problems, questions? e-mail olmstead at tr1tium.com this may have been useful...
last major update: 9/6/2016
13 sur 13 | 25/07/2021 à 12:00

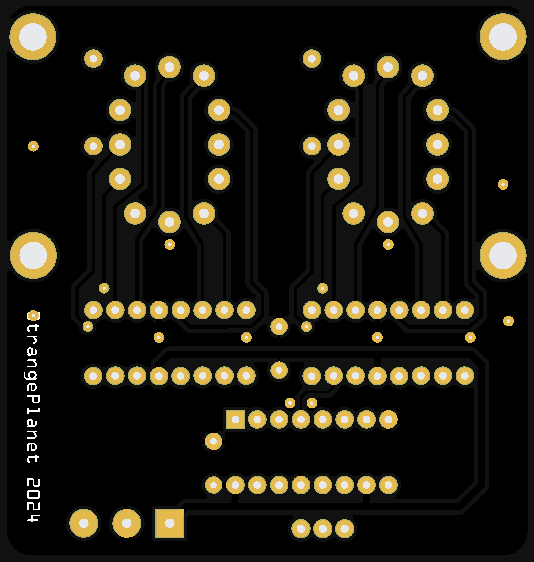
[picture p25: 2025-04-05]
Model 2025/images/bottom2.png

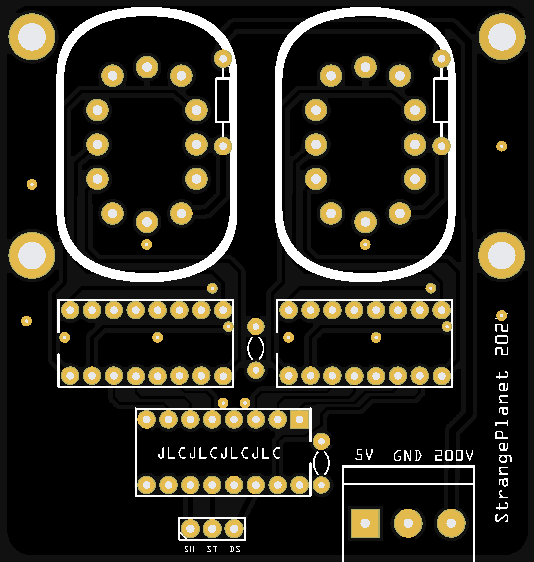
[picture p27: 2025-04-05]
Model 2025/images/top2.png

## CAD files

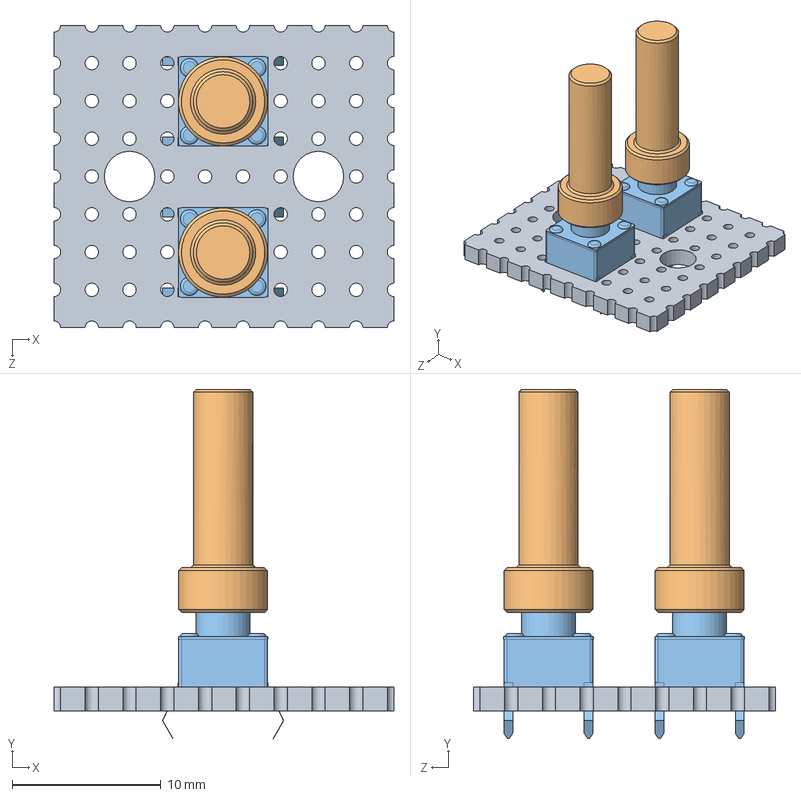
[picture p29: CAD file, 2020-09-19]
Model/button-support.SLDASM
22.9 x 23.5 x 20.3 mm
support-buttons
bouton x 2
6x6 mm x 2

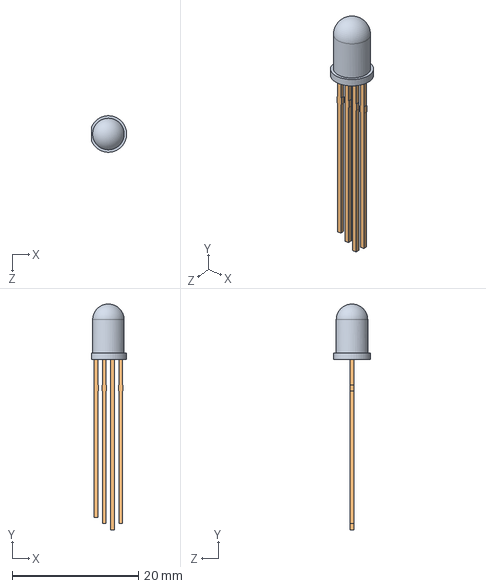
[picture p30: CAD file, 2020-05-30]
Model/Led RGB 5mm/Led RGB 5mm.SLDASM
5.59 x 35.8 x 5.79 mm
Lente^Led RGB 5mm
Terminais^Led RGB 5mm

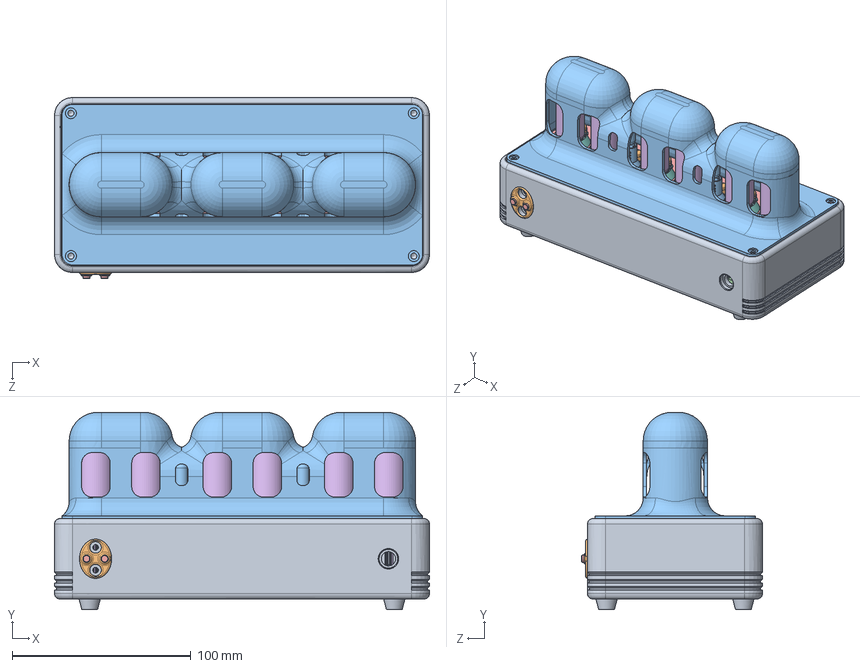
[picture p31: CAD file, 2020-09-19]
Model/clock.SLDASM
210.0 x 110.5 x 101.3 mm
coque
pcb
powerin
header x 6
plaque
NX-SZP-IN14-10-v01 x 6
NX-SZP-IN14-11-v01 x 78
NX-SZP-IN14-12-v01 x 6
NX-SZP-IN14-13-v01 x 6
NX-SZP-IN14-14-v01 x 6
NX-SZP-IN14-15-v01 x 6
NX-SZP-IN14-16-v01 x 6
NX-SZP-IN14-17-v01 x 6
NX-SZP-IN14-18-v01 x 12
NX-SZP-IN14-00-v01 x 6
NX-SZP-IN14-01-v01 x 6
NX-SZP-IN14-02-v01 x 6
NX-SZP-IN14-03-v01 x 6
NX-SZP-IN14-04-v01 x 6
NX-SZP-IN14-05-v01 x 6
NX-SZP-IN14-06-v01 x 6
NX-SZP-IN14-07-v01 x 6
NX-SZP-IN14-08-v01 x 6
NX-SZP-IN14-09-v01 x 6
NX-SZP-IN14-19-v01 x 6
NX-SZP-IN14-20-v01 x 6
NX-SZP-IN14-21-v01 x 6
NX-SZP-IN14-21-v02 x 6
Lente^Led RGB 5mm x 6
Terminais^Led RGB 5mm x 6
header-tube x 6
cache-tube x 6
calle-tube x 6
ecrou borgne x 16
NX-SZP-IN3-01-v01 x 2
NX-SZP-IN3-02-v01 x 4
NX-SZP-IN3-03-v01 x 2
NX-SZP-IN3-04-v01 x 2
NX-SZP-IN3-05-v01 x 2
NX-SZP-IN3-06-v01 x 2
tulipex2 x 2
support-indic x 2
cache-indic x 2
support-buttons
bouton x 2
6x6 mm x 2
touch-button
led-strip x 2
pied x 4
buttons-plate
cover

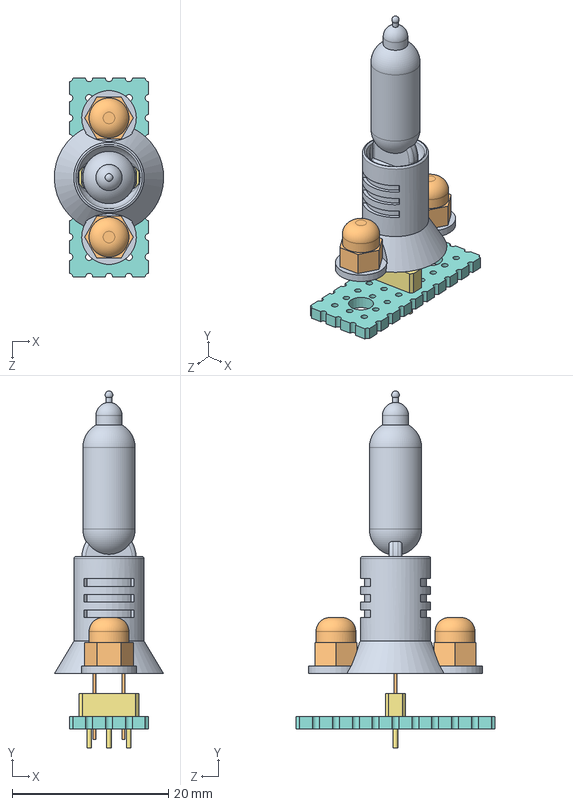
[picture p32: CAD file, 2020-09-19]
Model/indic+support.SLDASM
14.0 x 45.7 x 25.4 mm
NX-SZP-IN3-01-v01
NX-SZP-IN3-02-v01 x 2
NX-SZP-IN3-03-v01
NX-SZP-IN3-04-v01
NX-SZP-IN3-05-v01
NX-SZP-IN3-06-v01
tulipex2
support-indic
cache-indic
ecrou borgne x 2

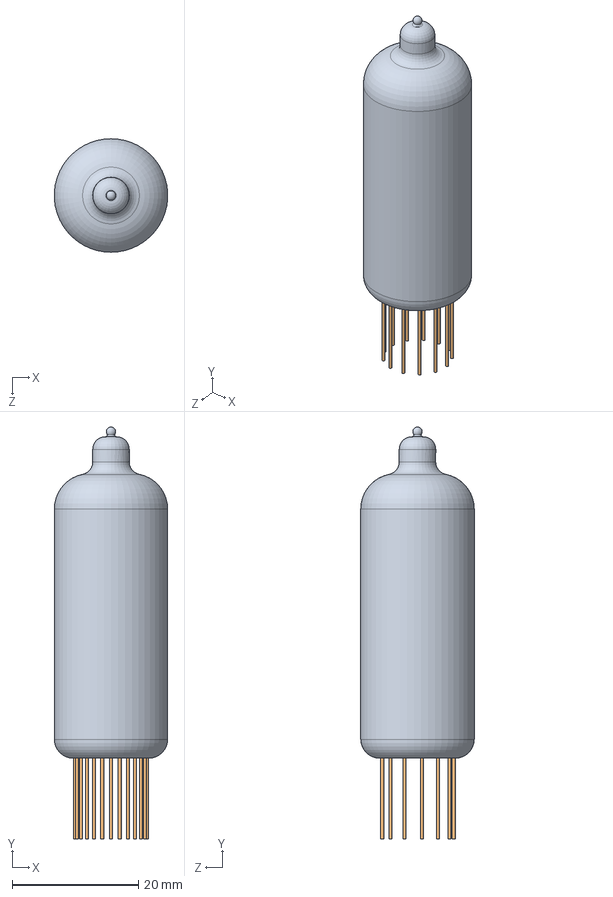
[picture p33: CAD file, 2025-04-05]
Model 2025/NX-SZP-IN14/NX-SZP-IN14-v01.SLDASM
18.0 x 65.3 x 18.0 mm
NX-SZP-IN14-10-v01
NX-SZP-IN14-11-v01 x 13
NX-SZP-IN14-12-v01
NX-SZP-IN14-13-v01
NX-SZP-IN14-14-v01
NX-SZP-IN14-15-v01
NX-SZP-IN14-16-v01
NX-SZP-IN14-17-v01
NX-SZP-IN14-18-v01 x 2
NX-SZP-IN14-00-v01
NX-SZP-IN14-01-v01
NX-SZP-IN14-02-v01
NX-SZP-IN14-03-v01
NX-SZP-IN14-04-v01
NX-SZP-IN14-05-v01
NX-SZP-IN14-06-v01
NX-SZP-IN14-07-v01
NX-SZP-IN14-08-v01
NX-SZP-IN14-09-v01
NX-SZP-IN14-19-v01
NX-SZP-IN14-20-v01
NX-SZP-IN14-21-v01
NX-SZP-IN14-21-v02

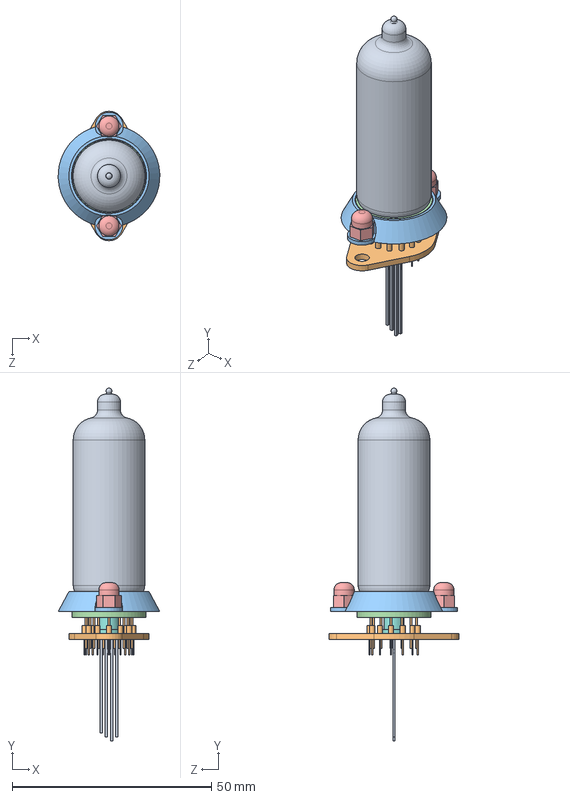
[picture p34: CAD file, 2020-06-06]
Model/tube+support.SLDASM
25.5 x 88.5 x 32.5 mm
NX-SZP-IN14-10-v01
NX-SZP-IN14-11-v01 x 13
NX-SZP-IN14-12-v01
NX-SZP-IN14-13-v01
NX-SZP-IN14-14-v01
NX-SZP-IN14-15-v01
NX-SZP-IN14-16-v01
NX-SZP-IN14-17-v01
NX-SZP-IN14-18-v01 x 2
NX-SZP-IN14-00-v01
NX-SZP-IN14-01-v01
NX-SZP-IN14-02-v01
NX-SZP-IN14-03-v01
NX-SZP-IN14-04-v01
NX-SZP-IN14-05-v01
NX-SZP-IN14-06-v01
NX-SZP-IN14-07-v01
NX-SZP-IN14-08-v01
NX-SZP-IN14-09-v01
NX-SZP-IN14-19-v01
NX-SZP-IN14-20-v01
NX-SZP-IN14-21-v01
NX-SZP-IN14-21-v02
Lente^Led RGB 5mm
Terminais^Led RGB 5mm
header-tube
cache-tube
calle-tube
ecrou borgne x 2

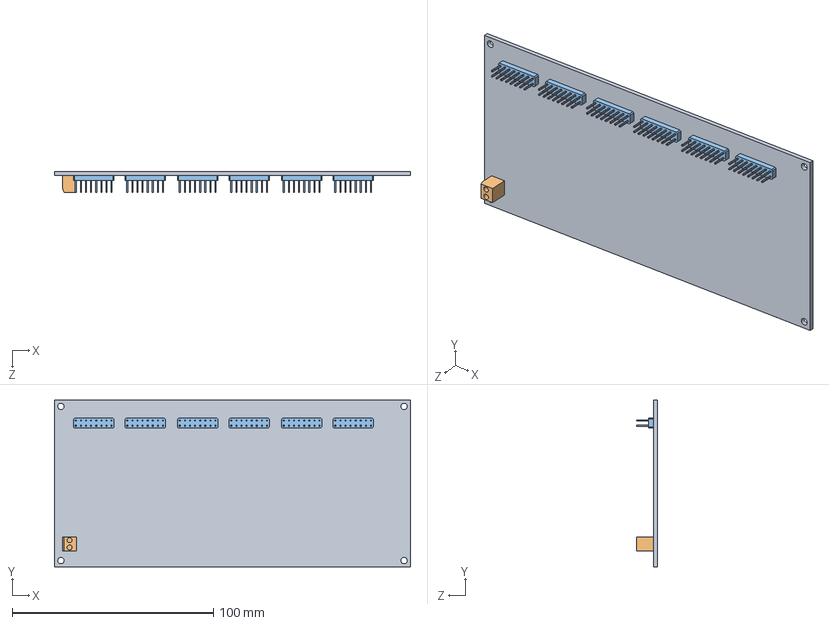
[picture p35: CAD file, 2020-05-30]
Model/carte.SLDASM
177.0 x 83.0 x 10.5 mm
pcb
powerin
header x 6

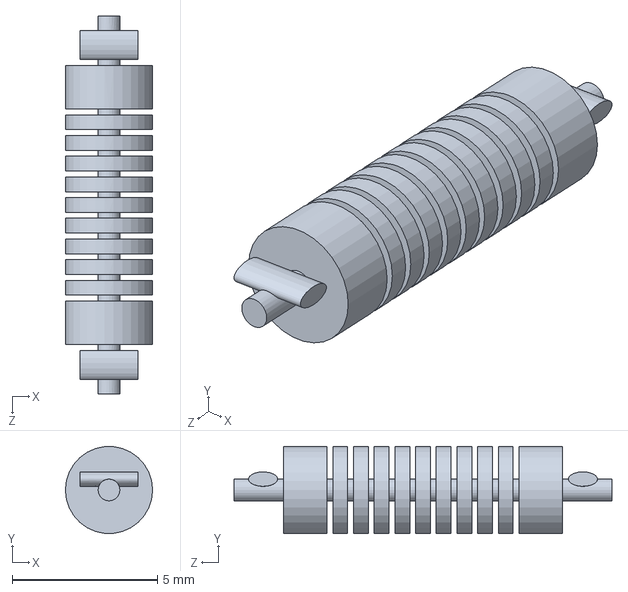
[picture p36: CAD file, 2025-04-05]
Model 2025/NX-SZP-IN14/NX-SZP-IN14-18-v01.SLDPRT
3.00 x 3.00 x 13.0 mm

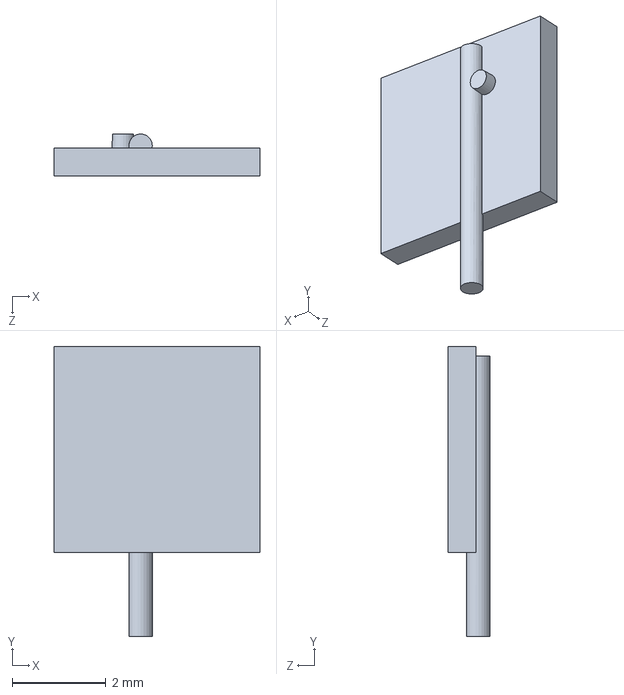
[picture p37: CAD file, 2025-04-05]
Model 2025/NX-SZP-IN3/NX-SZP-IN3-05-v01.SLDPRT
4.40 x 6.20 x 0.9 mm

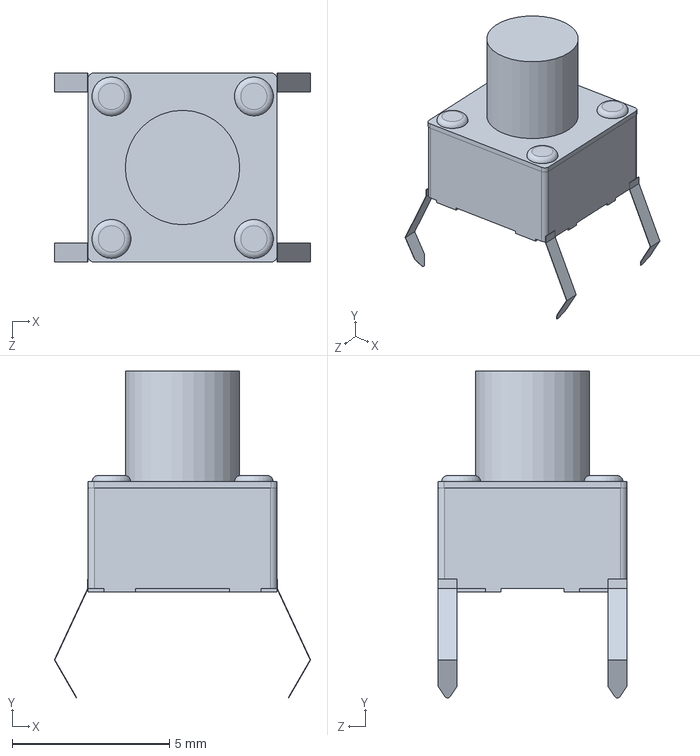
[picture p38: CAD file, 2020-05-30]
Model/push-button-6x6mm/6x6 mm.SLDPRT
8.15 x 10.4 x 6.02 mm

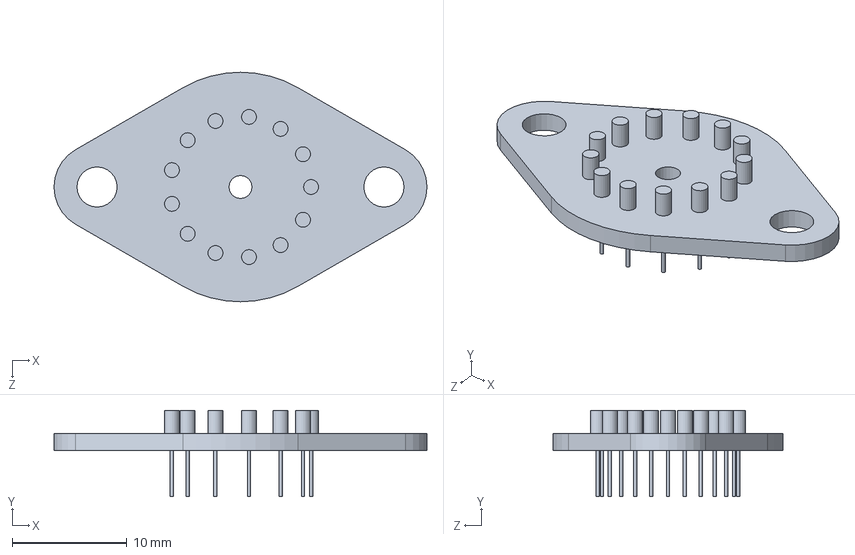
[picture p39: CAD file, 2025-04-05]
Model 2025/header-tube.SLDPRT
32.5 x 7.50 x 20.0 mm

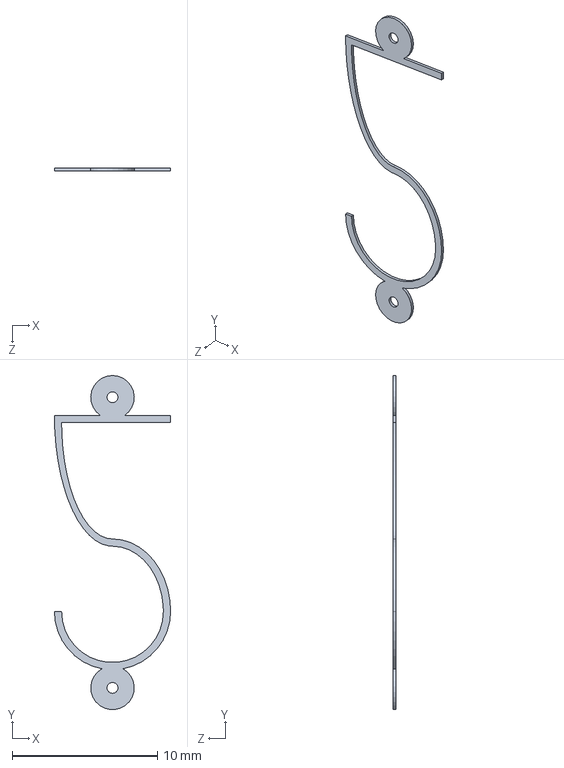
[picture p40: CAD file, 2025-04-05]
Model 2025/NX-SZP-IN14/NX-SZP-IN14-05-v01.SLDPRT
8.00 x 23.0 x 0.2 mm

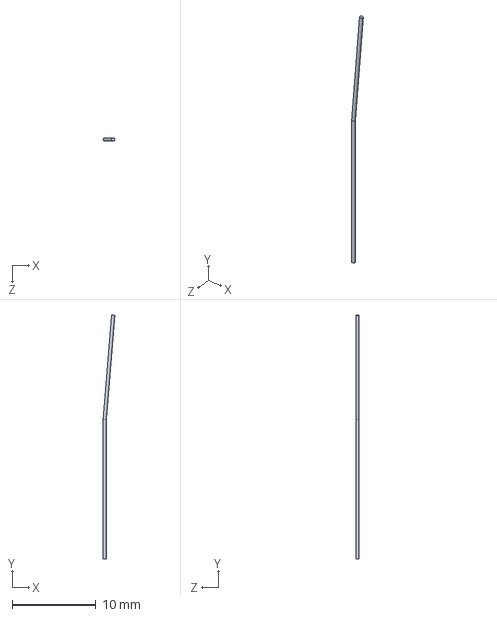
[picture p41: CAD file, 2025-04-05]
Model 2025/NX-SZP-IN3/NX-SZP-IN3-02-v01.SLDPRT
1.42 x 29.2 x 0.4 mm

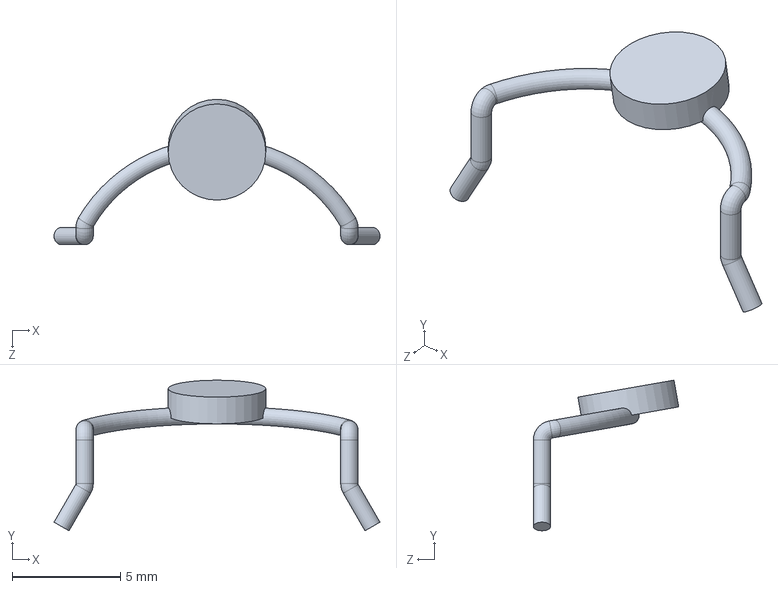
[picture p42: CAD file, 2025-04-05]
Model 2025/NX-SZP-IN14/NX-SZP-IN14-17-v01.SLDPRT
15.0 x 6.94 x 6.71 mm

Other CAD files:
Model 2025/indic+support.SLDASM
Model 2025/button-support.SLDASM
Model 2025/tube+support.SLDASM
Model 2025/NX-SZP-IN3/NX-SZP-IN3-03-v01.SLDPRT
Model 2025/NX-SZP-IN14/NX-SZP-IN14-00-v01.SLDPRT
Model 2025/NX-SZP-IN14/NX-SZP-IN14-01-v01.SLDPRT
Model 2025/NX-SZP-IN14/NX-SZP-IN14-02-v01.SLDPRT
Model 2025/NX-SZP-IN14/NX-SZP-IN14-03-v01.SLDPRT
Model 2025/NX-SZP-IN14/NX-SZP-IN14-04-v01.SLDPRT
Model 2025/NX-SZP-IN14/NX-SZP-IN14-06-v01.SLDPRT
Model 2025/NX-SZP-IN14/NX-SZP-IN14-07-v01.SLDPRT
Model 2025/NX-SZP-IN14/NX-SZP-IN14-08-v01.SLDPRT
Model 2025/NX-SZP-IN14/NX-SZP-IN14-09-v01.SLDPRT
Model 2025/NX-SZP-IN14/NX-SZP-IN14-10-v01.SLDPRT
Model 2025/NX-SZP-IN14/NX-SZP-IN14-11-v01.SLDPRT
Model 2025/NX-SZP-IN14/NX-SZP-IN14-12-v01.SLDPRT
Model 2025/NX-SZP-IN14/NX-SZP-IN14-13-v01.SLDPRT
Model 2025/NX-SZP-IN14/NX-SZP-IN14-14-v01.SLDPRT
Model 2025/NX-SZP-IN14/NX-SZP-IN14-15-v01.SLDPRT
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

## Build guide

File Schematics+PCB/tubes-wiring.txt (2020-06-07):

There are six 16 pins HE14 connectors with 3 different configurations (bad design !).
Each connectors use 4 pins for the RGB LED.

Seconds, minutes, hours :

  1 - - 0
  3 - - 2
  5 - - 4
  7 - - 6
  9 - - 8
 HV - - HV
  G - - B
GND - - R

10 seconds, 10 minutes :

  1 - - 0
  3 - - 2
  5 - - 4
 HV - - HV
    - -
    - -
  G - - B
GND - - R

10 hours :

  1 - - 0
    - - 2
    - -
 HV - - HV
 I1 - - HV I1
 I2 - - HV I2
  G - - B
GND - - R

I1 and I2 are the separators IN-3 tubes.

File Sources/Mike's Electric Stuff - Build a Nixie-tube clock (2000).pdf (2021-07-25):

Tour : click picture below for previous | Back to Mike's Electric Stuff | Click picture below for next

Ever felt that LEDs are a little 'cold' or 'plasticky'? Do you yearn for that warm, comforting glow that only ionized gas behind glass can provide? Do you have some nixie tubes gathering dust in your junk box (or in long-forgotten test equipment)? Well, now you can bring them back to life!

# Build a Nixie Tube Digital Clock

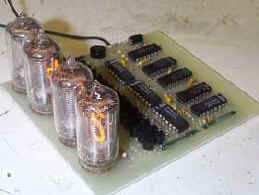
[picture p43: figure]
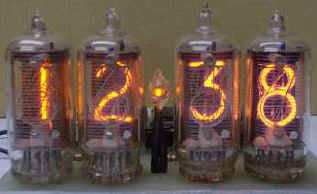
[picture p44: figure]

Warning! As this design uses a transformerless power supply, the whole circuit is at mains potential. Disconnect before making any adjustments etc. If you need to use an oscilloscope or other grounded instrument for debugging, the circuit MUST be operated through an isolating transformer. The finished design MUST be enclosed in a suitably insulated case, and if pushbuttons are used instead of reed switches for time-setting, they must have

mains rated insulation.

This information is provided 'as is'. Readers should only attempt to build this design if they are competent at electronics assembly and understand the dangers of mains voltages. No responsibility is accepted for any damage, injury or death (however serious) or disruption of the space-time continuum caused by anything remotely connected to this website.

A professional double-sided, through plated PCB is now available for this design -Please see here for more details. Please note that I cannot supply ready-built boards or clocks. If the idea of building your own scares you, check Logic Applied, Neontime Sphere Cosmodog wps Cathode Corner Dodocus Karlsson (click on 'living') , mapsevoli , nixieclock.net for ready-made ones or kits.
Another Nixie clock here. Have you built a nixie clock ? - add it to the Nixie Clock Gallery More info on building nixie clocks, including a seven-segment to nixie converter for modifying LED clocks. An Online nixie Clock. Nixie tube & driver sources and data Nixie clock emulator for Windows Nixie clock article in IEEE Spectrum magazine. A nixie tube cable TV box . An All-Valve nixie clock

This design uses no exotic or obsolete components other than the nixie tubes themselves. It was designed to be very compact, and does not use a mains transformer, allowing it to be built into a nice small case. It's designed for 230v (220-240V) mains operation, but can be modified for 115v (110-120V), and can be

Build a Nixie-tube clock | http://www.electricstuff.co.uk/nixclock.html
1 sur 10 | 25/07/2021 à 11:51

configured for 50 or 60Hz supplies.

Component cost should be well under UK£10/US$15 (excluding nixies). If it costs you much more, you're shopping in the wrong place!

The artwork for a PCB design can be downloaded, which can be built either 'flat' (above centre image), or cut in two and 'folded' (above right) to make a very compact unit. An additional version is available which comprises 2 stacked boards under the tubes (see pics at the bottom of the page).

To avoid the need for unsightly buttons on the case (and the need to isolate the mains voltage from the user), reed switches are used for the time-setting function, these being operated by holding a magnet against the case, near the appropriate switch. (Any excuse to get some more glass bits on the PCB...!)

## Circuit description

Click Here for .PDF file of the circuit schematic (39K). This should print legibly at A4 (Letter) size.

If you don't care how it works, skip this section, but please don't, as you may learn something...
The circuit uses CMOS 4017 counters to divide the 50Hz (or 60Hz) mains frequency down to 1Hz, and also to generate the 1-of-10 drive signals to drive the tubes. The high-voltage driver stages use readily available low-cost MPSA42 transistors. IC drivers (like the TTL 74141) were not used for reasons of cost, availability and power consumption.

The 230V mains supply is rectified to produce an unsmoothed +340V peak-to-peak supply for the nixie tubes. Smoothing is not required as the 100Hz flicker will not be visible, it reduces the avarage power dissipation in the anode resistors R5-8, and avoids the need for a physically large capacitor. For 115V operation, a voltage-doubler is required, producing a fairly smooth +250VDC supply. The low-voltage supply for the CMOS ICs is derived from a resistor/zener dropper R1/2 and D1. (2 resistors are used to avoid exceeding the resistors' voltage rating). One or two NE-2 lamps provide a flashing dot or colon indicator. You could alternatively use the decimal point of the 'hours' nixie, but you will probably need to connect it via R3 to match the digit brightness, and you may find that the brightness of the hours digit fluctuates slightly as the dot switches on and off.

The 50Hz signal is current-limited by R11/12, and buffered by U8B, which is just being used as a buffer stage to buffer the high-impedance 50/60Hz signal for use by the fast-set switch. U8B's CMOS input static-protection diodes clamp the voltage to the supply rails. C5 filters out fast mains transients and noise. C2/R10 and D5 reset the hours count to '1' when it reaches '13'. R9 allows the 'minutes' clock signal to be overridden by the time set buttons. R13 and C6 form a low-pass filter to reduce the effect of switch-bounce on the slow-set switch.

Note the different connection of the hours tube to U1, as hours count from 1 to 12, whereas the minutes count from 0 to 59.

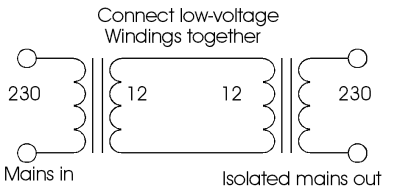
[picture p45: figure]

As the circuit is not isolated from the
mains, it is ESSENTIAL to use an
isolating transformer if you need to connect an instrument such as an oscilloscope. As the circuit draws only a small current, you can easily make a suitable isolating transformer using two identical (i.e. same secondary voltage) small low-voltage mains transformers with the secondaries connected together. When connected via an isolating transformer, you can earth the 0V signal
2 sur 10 | 25/07/2021 à 11:51

ground line. Remember that there will still be dangerous voltages on the board!

## PCB

Information is provided here to make your own PCB for this design. The design can be built as a single PCB, or the tube section can be seperated to make a compact unit with the electronics vertically mounted behind the tubes. The main part of the board can also be seperated and hard-wired to tubes with different pinouts to the ones I used.

The display part of the PCB is designed for the tubes I had available, which are fairly standard size 'generic' ones with no maker's name. I have subsequently found that ITT GNP-17A and Hivac XN11 tubes have the same pinout as the ones I used. They have 12 pins (0-9, point, anode). Some nixies have 13 pins -the extra electrode is a 'primer', used to maintain ionisation to avoid flicker on multiplexed displays. This electrode is not necessary in this application and can be left unconnected. The PCB component layout drawing has the pinouts of the tubes I used marked.
The leads of wire-ended tubes with different pinouts can usually be pre-formed to fit the PCB, but you won't be able to seat the tube hard against the PCB. For tubes with solid pins, you'll probably need to either make up your own display PCB section, or hardwire them with or without sockets. See later for a hint on making DIY sockets.

The PCB is single-sided, and was designed to be very compact, and therefore has a rather high track density, so it needs to be made very carefully. See here for lots of info on making good-quality homebrew PCBs.

Pcb data files for download
(PCB files corrected 31/10/99 - 60Hz link goes to pin 5, was pin 6 on old PCB)
Component layout drawing : nxlayout.pdf (192K).
PCB artwork (x1, view from component side, so print side faces copper) :
nixpcb.pdf (87K) PDF format - ensure 'fit to page' is off when printing. you may need to scroll to bottom of page to see image.
nixgrb.zip (10K) Zipped Gerber photoplot file (embedded apertures)

Alternative version - PCB is cut at a different point so both PCBs end up the same size, to allow PCBs to be stacked underneath tubes - see images at bottom of page. Component layout drawing nixlay2.pdf (192K) PCB artwork nix2pcb.pdf (90K)

nixdxfs.zip (51K) Zipped DXF files of both versions of the PCB. Note that the quality of DXF-Import in many software packages is poor, so you may have problems with line-widths & pad shapes. Use the PDF if you can.

Email if you need a different file format & I'll see what I can do.

The PCB artwork must be printed at a resolution of at least 600dpi. Check the printout for accurate size using the dimensions printed outside the board area. If you can't get a sufficiently good quality printout with your printer, print the PDF file using a Postscript printer driver, configured to print to a file, and take this file to a typesetting beaurau (look under 'desktop publishing services' in the Yellow Pages) and ask for a positive film - this should cost about UK£5 (US$8), and will produce an excellent quality transparency for UV exposure.
Drill sizes are all 0.8mm except D4 (1.0mm), and the holes for the mains input (1.2mm or to suit cable). If building the 'folded' version, drill the interconnect pins to 1.0mm and use a standard 0.025" square-post header strip.

All the parts for this design (apart from the nixies) can be obtained from any normal component suppliers including Maplin, RS, Farnell and many others worldwide.

3 sur 10 | 25/07/2021 à 11:51

See here for a list of possible nixie sources and pinout information.

## Parts list

Parts marked * are for 115V doubler version only, parts marked + for 230V version (or 115V via transformer).

Qty | Ref | Description | Typical mail-order price each, UK Pounds (multiply by approx 1.5 for US$)
7 | U1-7 | 4017 (MC14017, CD4017, HEF4017 etc.) | 0.50-0.80
1 | U8 | 4013 (MC14013, CD4013, HEF4013 etc.) | 0.30-0.50
1 | D1 | 4V7 (=4.7 volt) 400mW Zener diode | 0.05-0.10
2 | D2*,D3* | 1N4005,6 or 7 diode | 0.05-0.10
1 | D4+ | W04,5,6 or7 bridge rectifier (1 Amp, 400V or more) | 0.30-0.50
1 | D5 | 1N4148 or 1N914 signal diode | 0.02-0.05
1 | C1 | 100uF 10V electrolytic capacitor, radial pins | 0.05-0.10
3 C2,5,6 | | 1nF ceramic capacitor, 0.1" pin spacing NB C2 may not be required - fit only if hours don't roll over correctly (see notes later) | 0.02-0.08
2 | C3*,C4* | 2.2uF 350VDC electrolytic or polyester/polyprop. capacitor. (not 250v as shown on schematic). | 0.30-0.60
3 | C7-9 | 100nF ceramic capacitor, 0.2" pin spacing | 0.02-0.08
3 | R1,2,9 | 100K 0.125 or 0.25 watt resistor, 5% | 0.01-0.02
2 | R3,4 | Resistor to suit colon neons, around 680K 1/4W See below | 0.01-0.02
4 | R5-8 | Resistor to suit nixies, around 47K, see below | 0.01-0.02
2 | R10,13 | 10K 0.125 or 0.25 watt resistor, 5% | 0.01-0.02
2/3 | R11,12, R14* | 1M 0.25 watt resistor, 5% | 0.01-0.02
1 | R15* | 220R 0.25 watt resistor, preferably fusible (flameproof) type 5% | 0.05-0.10
1 | R16+ | 1K 0.25 watt resistor, preferably fusible (flameproof) type 5% | 0.05-0.10
28 | R17-44 | 33K 0.1 or 0.125W sub-miniature resistor 5% | 0.01-0.02
28 | Q1-28 | MPSA42 transistor (300V Vceo, TO-92) | 0.05-0.15
4 | V1-4 | Nixie tubes
2 | LP1,2 | NE-2 or similar neon bulb | 0.20-0.30

## Assembly Notes

If you intend to build the PCB as a 'vertical' version, it is suggested that you build & test it as a single PCB, for ease of access to components, then cut the board into the two parts when you've got it working.

The PCB has a high track/component density, and needs careful soldering with a fine tip. Check carefully for shorts, ESPECIALLY from the high-voltage anode supply (junction of R5-8), as a short from this line

4 sur 10 | 25/07/2021 à 11:51

could cause severe damage or fire!
There are several wire jumper links on the PCB. these are made with tinned-copper wire (or component lead offcuts). If using a reel of TC wire, you can get nice straight links by stretching the wire slightly - this is easy to do if you unroll a foot or so, and pull it tight with pliers, then cut to short lengths.
Take care when bending the leads of the reed switches - it is very easy to crack the glass. Use fine-nosed pliers to hold the lead between the glass and the bend.

If you mount the nixies close up against the PCB, do not solder the leads at the
point where they come through the PCB, as this can cause mechanical stress
and cracking. Instead, fold the wires over and solder to the larger outer pads, as shown on the right.

Many nixies have short, solid pins instead of wires - do not attempt to solder directly to this type of tube pin, as you run a high risk of cracking the glass. To connect to tubes like this, the socket contacts from a dismantled a 'D' type socket (the type with turned pins, not the cheap stamped-pin ones) provide an easy method. You could either just hardwire to the pins, make a PCB to hold them, or epoxy them into holes drilled into a plastic or fibreglass sheet to make a proper socket.

The driver area is very densely packed - use
subminiature (1/8 watt) 33K resistors if possible. See the close-ups (right). If you use larger 1/4 watt resistors, you may need to space the transistors off the PCB slightly.

It may be necessary to experiment with the value of the anode resistors R5-8, so don't
solder them all in - just tack R8 in place, and
check that the tube brightness is acceptable.

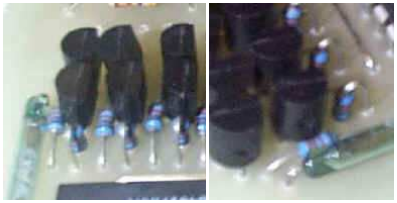
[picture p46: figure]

If you see any significant purple 'haze' in the tube, or parts of the tube other than the digits lighting, the current is too high, and you should increase the resistor value. Avoid the temptation to run the tubes too brightly, as this will make the glass blacken and reduce their life considerably. Check for tube blackening after running the clock for a few months. Recommended values to start with : 47K (R5-8), 680K (R3,4). For the 115V voltage-doubler version, these will probably need increasing. If you are using larger tubes, you will probably need to decrease R5-8, and possibly use higher wattage versions (1 watt) to cope with the extra power dissipation.
If you have found suitable values for specific tubes and power supplies, please let me know. Values sent by other builders : ZM1000/230VAC : 68K. National NL5859/115v with doubler 200-220K. Burroughs B5991/115v with doubler:100K. Hivac XN11/240V:150K. 5807, 115v with doubler 100K.

The 4017 counters can power up in 'strange' count states. This means that on power-up, the clock may show an invalid time, or even multiple digits lit in one tube. Use the 'Fast Set' mode to increment the display until it is sensible. The counters in the divider network may also assume odd states, so the first 'minute' after power up could be either short or long! For optimum accuracy, wait until the minute display changes before setting the time.

One builder has reported a problem with the hours not resetting properly, i.e. going 9,10,11,12,3,4,5. I think this was due to timing differeces between the makes of 4017 and 4013 used for U1 and U8. This was fixed by adding a 220pF capacitor between pins 15 and 16 of U1. (If you have this problem, you may find that a smaller value could be required, e.g. 100pF). Another person reported the hours count going 9,10,11,12,1,2,1,2 which was fixed by removing C2.

5 sur 10 | 25/07/2021 à 11:51

Thanks to Steven Rougier for this alternative fix for this issue : Disconnect pin 15 of U1 from the rest of the circuit and connect it to
pin 5 of U8A via a 1n capacitor. Also, connect pin 15 of U1 to ground via a 10k resistor. C2 and the 220pF are not required. The clock will then always roll over correctly since U1 will reset U8B and U8B will then reset U1, in sequence rather than in parallel. With the parallel situation, the first i.c. to reset removes the reset signal from the other and unreliable results can occur.

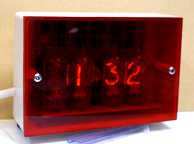
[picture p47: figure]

A nice easy way to make a case is to get a standard plastic project box of an
appropriate size, and replace the lid with a piece of light-red or orange
tinted clear plastic, cut to the correct size. For UK builders, an alternative might be to to use a surface double 13 amp mains socket back-box. If you can't find tinted plastic (sign shops are a good source), use clear plastic, with a sheet of cellophane or stage-lighting gel filter material behind it. If you want to make a 'window' instead of having the whole front clear, mask
a suitable rectangle with tape and spray the inside of the plastic sheet black.
A black card placed behind the tubes will also improve appearance.

Remember that the entire circuit is at mains potential, so take care that any external screws cannot come into contact with the circuitry. If you use pushbuttons instead of reed switches, they MUST be mains-rated, and be sufficiently well constructed that minor damage (e.g. cap coming off) will not cause live parts to be exposed.

## Suggestions for modifications

115V mains operation
A voltage doubler is
required to get sufficient voltage for the tubes,
and this is shown on the
schematic, but not
included on the PCB. (it
is included on the ready-

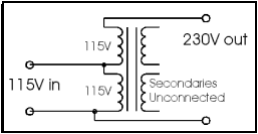
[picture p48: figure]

made PCB) Note that the schematic shows C3,4 as 250V rated
- this should be 350V. You can add the doubler to the PCB as a slight 'bodge', as shown on the left. This uses half of the bridge rectifier for the two diodes D2,3.
Alternatively (right), use a small dual-primary mains transformer wired as a 115-to-230v autotransformer (secondary unconnected), this will allow the PCB to be used unmodified. Power draw is

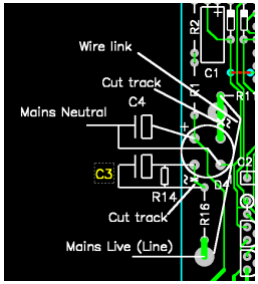
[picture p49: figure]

low, so any transformer larger than about 4.5VA will do, and you may be able to fit it into a mains adapter ('wall wart') type casing.

Seconds display : For a six digit clock with seconds, connect another two nixie tubes to the outputs of U5 (secs) and U6 (tens), via another 16 driver stages. You'll need a way to reset the seconds count when setting the time - I'll let you figure this out (email me if you really want to do this & can't work out how to!) UPDATE: I've just noticed that the divider circuit isn't configured to be able to do this - it divides by 6 then ten, but should do it the other way round. This is easy enough to fix - swap the RST pin connections between U5 and U6, i.e. connect U5 RST to ground, and U6 RST to U6 Q6. Connect U6 CLK to U5 CO instead of Q0. Take R9 to U6 Q5 instead of CO. Alternatively, make up just the minutes section of a second PCB, with just U2/U3 and their respective drivers fitted, and use this as the seconds divider and display, omitting U5/6 from the main PCB.
There is a revised schematic showing the correct divider arrangement, together with a means of adding a 'seconds hold' function to allow exact time setting in the schematic for the ready-made pcb.
6 sur 10 | 25/07/2021 à 11:51

24 hour display format : Change connections from U1 and the 'Hours' nixie to match those for U3 (we need to count 0..23 instead of 1..12). Replace U8A with another 4017 (U9), with outputs Q1 and Q2 connected to the '1' and '2' electrodes of the '10 hours' tube, using an extra driver stage along with the current '1' stage. Connect the RST input of U9 to the RST input of U1. Connect the top end of the R10/C2 pair to the 'Q4' output of U1 (so it resets at 24), and the cathode of D5 to the Q2 output of U9.

AM/PM display You need an extra 4013 to act as an AM/PM latch. Connect D to /Q on the new 4013, and tie the S and R pins low. Connect a 10K resistor from U1 pin 2 to the new 4013's clock pin. This will generate a rising edge whenever the hours digit goes to "2", i.e. at "12" and "02." Connect a diode with the cathode (ring) to U8A pin 1 and the anode to the new 4013's clock pin. This will hold the clock low (inactive) when the 10-hours digit is off, so you only get a clock pulse on "12" and not "02." Connect the Q and /Q pin of the new 4013 each to their own driver transistor network. Use these to each drive one of two /PM AM neon bulbs, which will toggle at midnight and noon. Connect S,R,D and Clock inputs of the unused half of the 4013 to ground, otherwise they will float and draw excess current.

Radio controlled timebase WWVB (USA) check out Jeff Thomas' site for a mod to use the innards of a cheap radio-controlled clock as a timebase. This method should also be viable for the UK 60KHz and German DCF77 time standards, using locally bought clocks.

Automatic dimming See Here for a neat mod to dim the tubes according to ambient light level.

Here are a few assorted pictures to clarify any details not obvious from the layout drawing. Note that there are a couple of slight differences in the positions of a few of the components due to errors on the prototype PCB, and only one of the 'colon' neons is fitted.

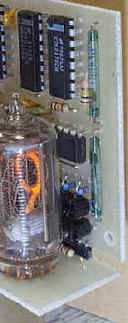
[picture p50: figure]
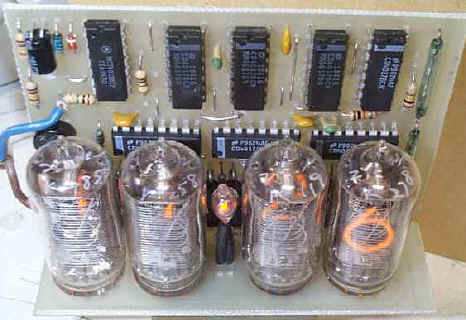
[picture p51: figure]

7 sur 10 | 25/07/2021 à 11:51

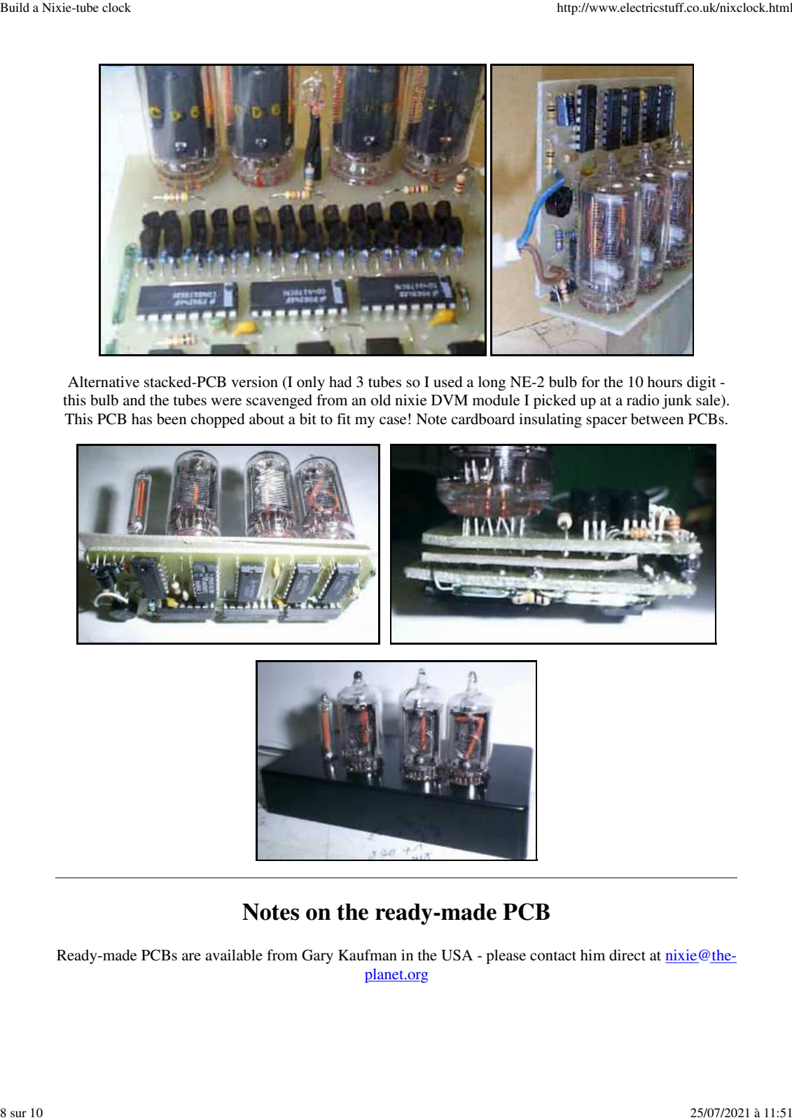
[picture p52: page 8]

Alternative stacked-PCB version (I only had 3 tubes so I used a long NE-2 bulb for the 10 hours digit -this bulb and the tubes were scavenged from an old nixie DVM module I picked up at a radio junk sale). This PCB has been chopped about a bit to fit my case! Note cardboard insulating spacer between PCBs.

## Notes on the ready-made PCB

Ready-made PCBs are available from Gary Kaufman in the USA - please contact him direct at nixie@the-planet.org

8 sur 10 | 25/07/2021 à 11:51

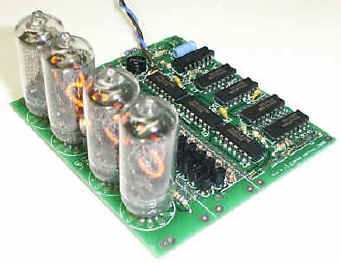
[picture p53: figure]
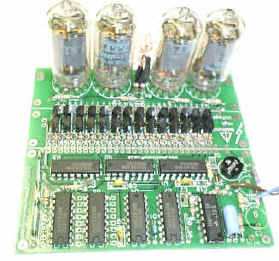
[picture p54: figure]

The design for this PCB has been enhanced from the original version to make it as flexible as possible. Changes include the addition of mounting holes, optional voltage doubler for 115v operation, two possible cut-points to subdivide the PCB to suit various mechanical arrangements, and a rearranged divider and connection pads to make it easier to add seconds digits for a 6-digit version.

If you will be using this PCB, please download nixiepcb.zip (400K), which contains PDF component layout drawings and a revised schematic for the PCB.

The parts list is as shown above, with the following changes : R14 deleted (R14 is now only used for the 6-digit seconds option). C10 (100 to 220pF) added - this may be required with some makes of U1/U8 if the hours don't reset correctly from 12 to 1. Note that the legend for C5 is missing from the silkscreen - it's next to R12

The PCB can be built up as a 115 or 230v version. See Voltage_Options.pdf (in nixiepcb.zip) for component differences.
Note that only one of these two options can be fitted!

The PCB can be cut at one or both of two possible lines for flexibility of packaging - see Layout_Options.pdf (in nixiepcb.zip) for some suggested layouts.

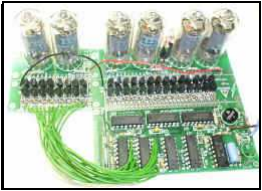
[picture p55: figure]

## Seconds option

The PCB has pads to provide the signals to drive another 2 nixies for a seconds display. These signals are connected to another sixteen driver stages to drive the 2 tubes. These 2 digits can be built on a second PCB, cut-down as required. Download seconds.pdf for a diagram of the required interconnections.
For time setting, in addition to the normal fast/slow set switches, an additional switch is used which freezes the seconds count.A 100nF capacitor may be required across the 'Seconds Hold' switch, depending on the type of switch used, to avoid the count
jumping when the switch is operated.

This design can, with some small mods, also be used to drive low-voltage filament displays, like projection units or the light-guide ones shown below. Assuming a 12V filament display, the basic changes are to use BC548's instead of MPAS42 drivers (note different pinout), and reduce the base resistors to about 2K2. The circuit is run from a 9VAC 500mA transformer fed into D4, R1/2/16 are bypassed, D1

9 sur 10 | 25/07/2021 à 11:51

omitted and C1 increased to 1000uF 16V. The CMOS chips will now run at 12V (maximum is 15V so be careful if using higher voltage displays).

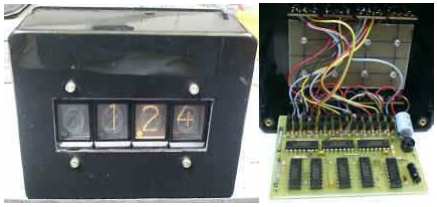
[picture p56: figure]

Nixie Clock Gallery

Click picture above for Previous | Back to Mike's Electric Stuff | Click picture above for next
10 sur 10 | 25/07/2021 à 11:51

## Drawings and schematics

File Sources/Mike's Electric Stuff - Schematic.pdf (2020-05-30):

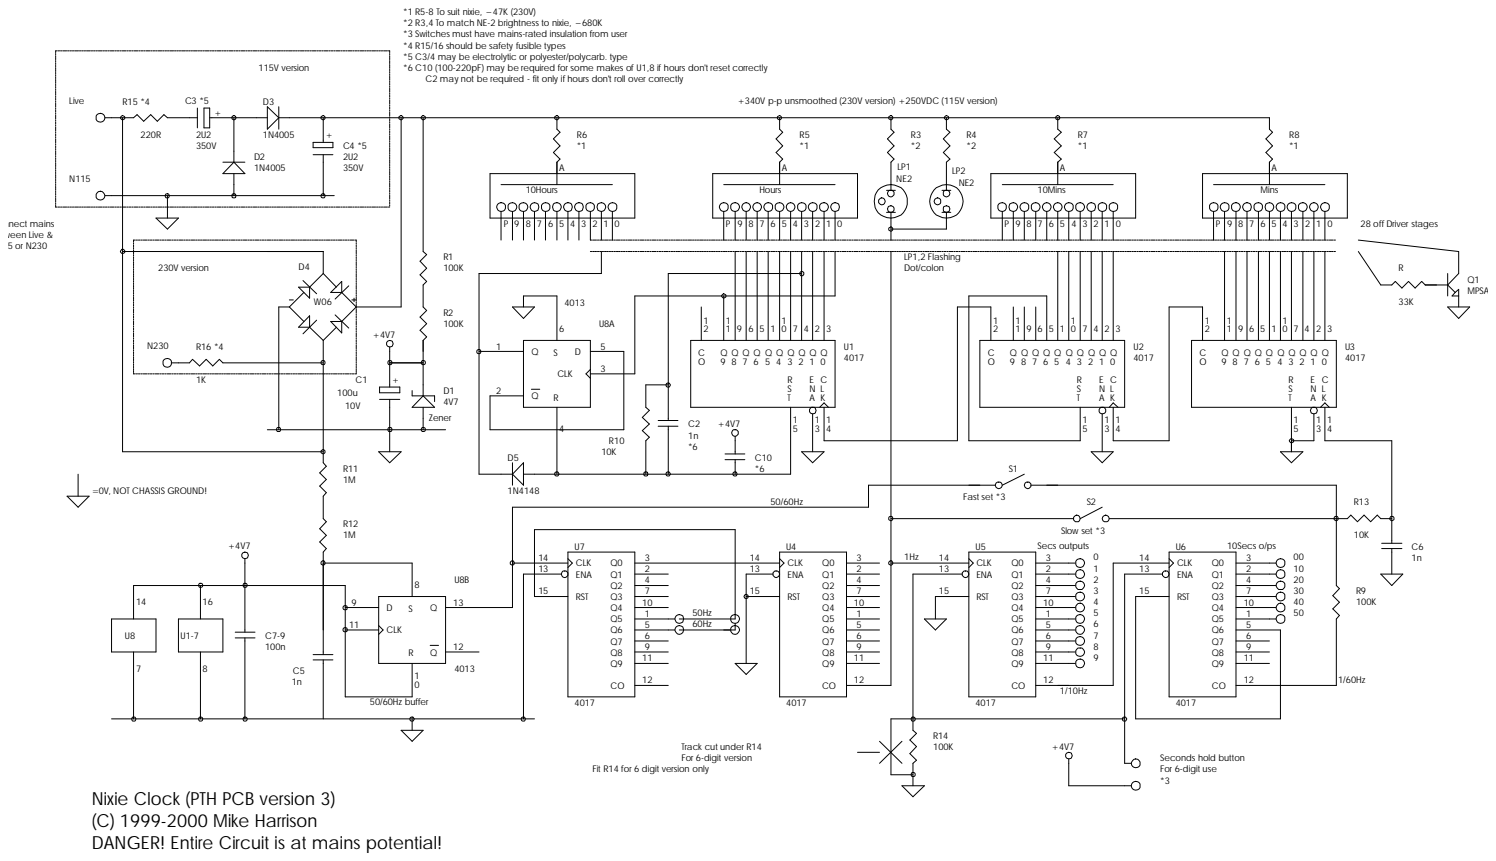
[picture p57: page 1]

*1 R5-8 To suit nixie, ~47K (230V)
*2 R3,4 To match NE-2 brightness to nixie, ~680K
*3 Switches must have mains-rated insulation from user
*4 R15/16 should be safety fusible types
*5 C3/4 may be electrolytic or polyester/polycarb. type
*6 C10 (100-220pF) may be required for some makes of U1,8 if hours don't reset correctly
C2 may not be required- fit only if hours don't roll over correctly

Fit R14 for6 digit version only

Nixie Clock (PTH PCB version 3)
(C) 1999-2000 Mike Harrison
DANGER! Entire Circuit is at mains potential!

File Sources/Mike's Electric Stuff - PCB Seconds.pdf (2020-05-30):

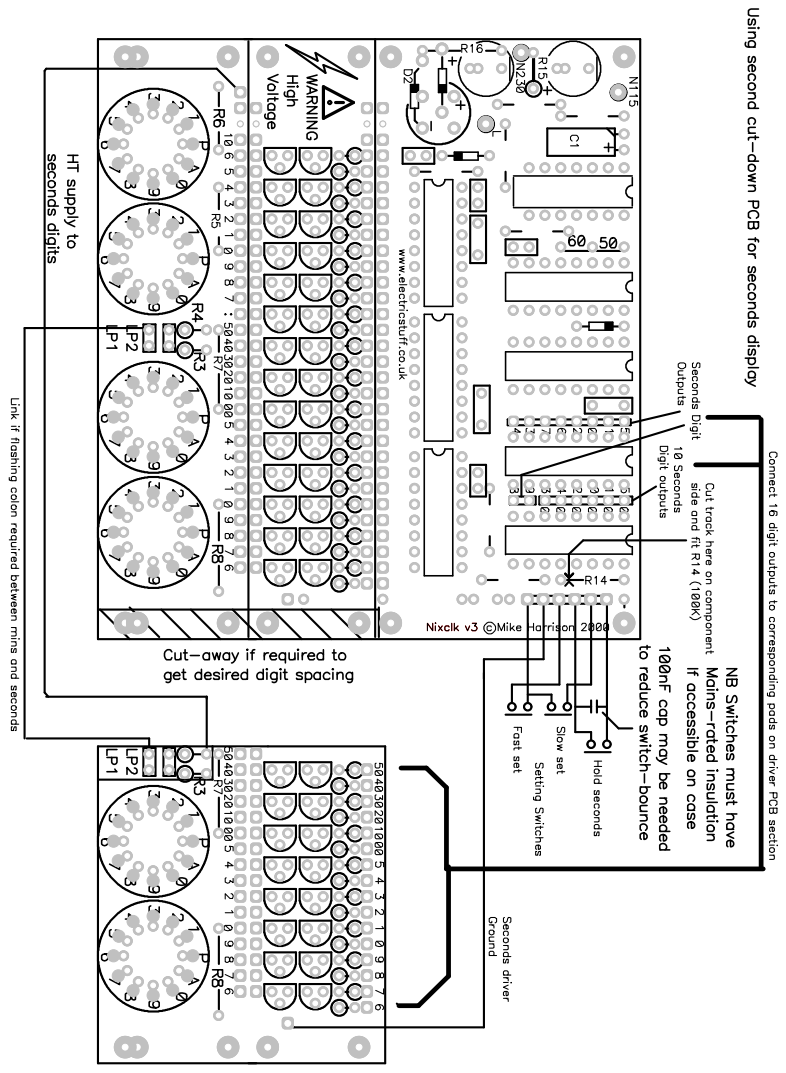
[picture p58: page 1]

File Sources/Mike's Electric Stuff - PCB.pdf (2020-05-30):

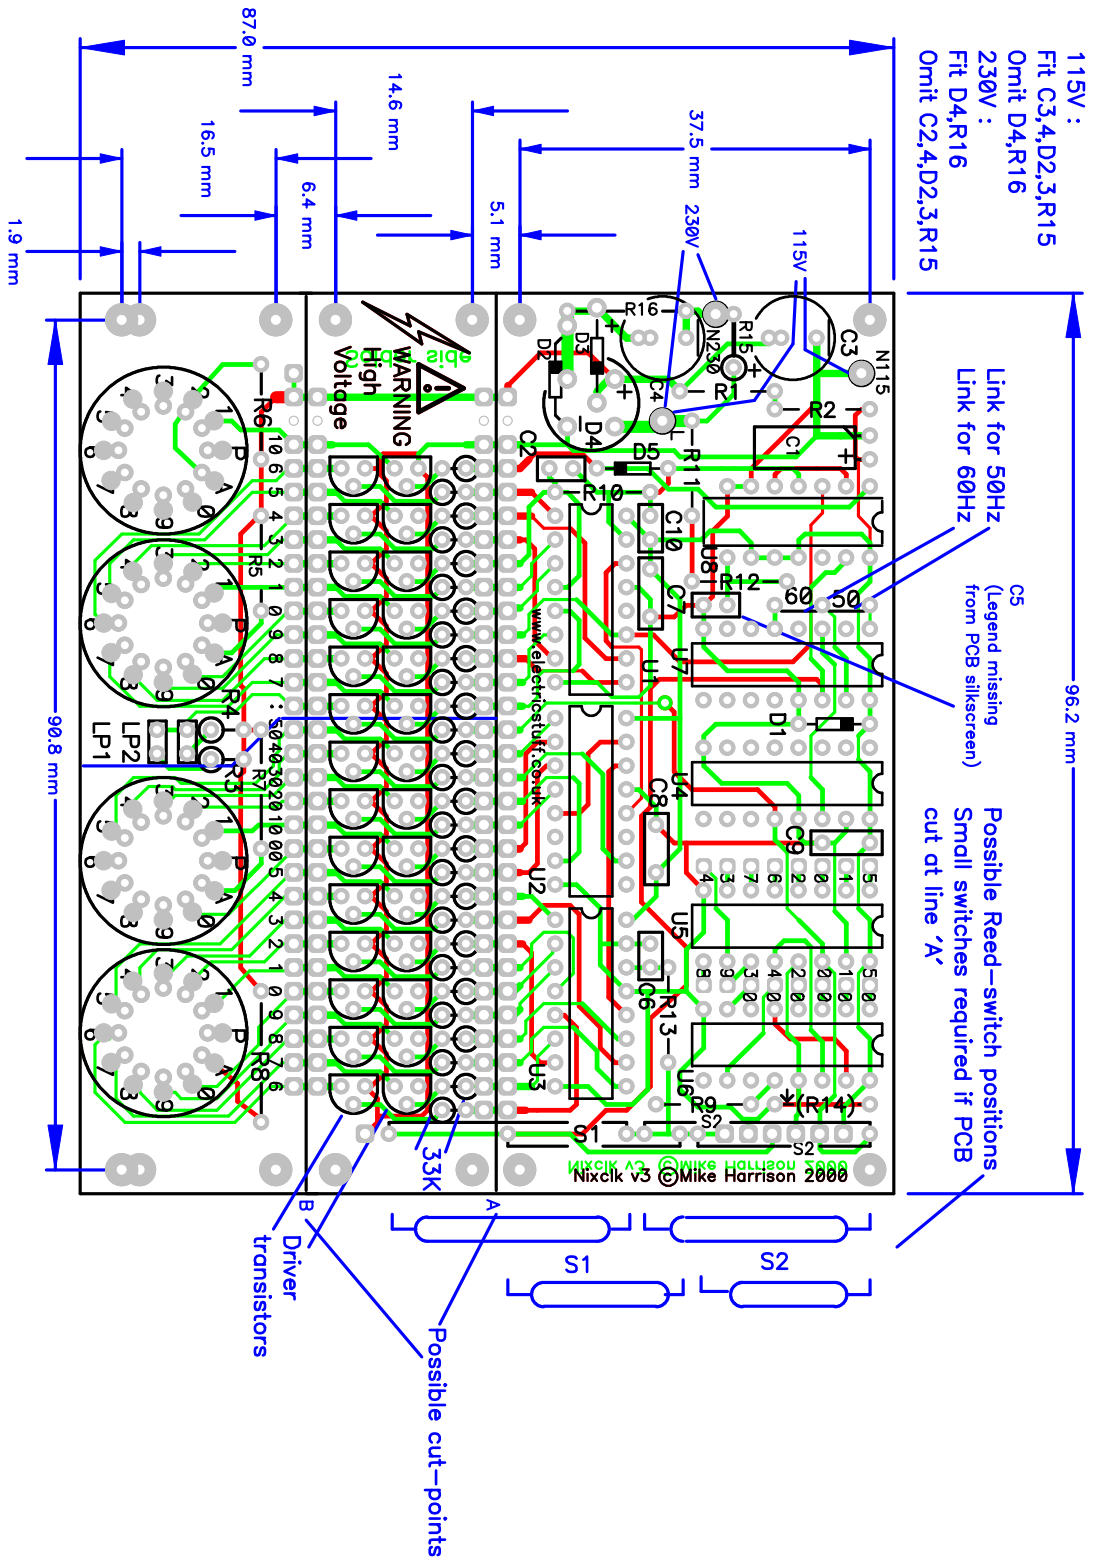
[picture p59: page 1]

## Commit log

2020-05-31 Fix model
    [button-support.SLDASM, clock.SLDASM, plaque.SLDPRT]
2020-06-06 Update model
    [buttons-plate.SLDPRT, clock.SLDASM, indic+support.SLDASM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]
2020-06-08 Finish legs
    [clock.SLDASM, pied.SLDPRT]
2020-09-19 Add transport cover
    [button-support.SLDASM, clock.SLDASM, cover.SLDPRT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]
2025-04-05 New 3D model
    [NX-SZP-IN14-00-v01.SLDPRT, NX-SZP-IN14-01-v01.SLDPRT, NX-SZP-IN14-02-v01.SLDPRT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]
